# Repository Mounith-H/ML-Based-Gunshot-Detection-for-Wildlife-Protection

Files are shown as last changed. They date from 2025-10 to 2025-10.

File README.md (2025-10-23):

# AI-Powered Edge Gunshot Detection for Wildlife Protection

## Short summary
This repository contains firmware, hardware integration code, and supporting artifacts for an edge device that detects gunshot-like events using a Raspberry Pi Pico. The device performs on-device audio capture and inference, attaches GPS coordinates, and reports events over an NRF24L01 wireless link. The primary goals are real-time detection, low power operation, and field deployability for anti-poaching monitoring.

## Status
- Development: Feature-complete for core sensing, radio communication, GPS and power management on the Pico hardware.
- Machine learning: A TensorFlow Lite quantized model and export artifacts are provided; on-device inference integration is in progress.

Key completed items
- Audio input: INMP441 I2S microphone with PIO/DMA sampling.
- Location: NEO-6M GPS integration and basic NMEA parsing.
- Radio: NRF24L01 packet transmission with fragmentation and retries.
- Power: IP5306 power management using a PIO-driven PWM (continuous KEY pulsing) for reliable operation.
- Architecture: Dual-core Pico split (system/core tasks and audio/inference tasks) with robust initialization and error handling.

Planned / in development
- Finalize TensorFlow Lite inference on Pico and optimize model runtime.
- Optional mesh networking, encryption and acknowledgments.

## Repository contents (high level)
- `Raspberry_pi_pico/`, `inference-app/` – Pico firmware and build files.
- `python/` – training artifacts, quantized model (`gunshot_model_quant.tflite`), and helper notebooks.
- `python/dataset/` – dataset organization (environment and gunshot recordings) used for model training (see Data Availability).
- `figures_data/`, `metrics/` – plots, model metrics and training logs.
- `PCB/`, `lib/` – hardware design files and helper libraries.

## Data Availability (journal-ready statement)
All code required to build and run the device is included in this repository. The following datasets and artifacts are available as follows:

- Trained model: A quantized TensorFlow Lite model is included in `python/gunshot_model_quant.tflite` and additional exported models are in `python/exported_models/`.
- Processed training artifacts (training logs, metrics, and figure data) are included in `figures_data/` and `metrics/`.
- Raw audio recordings used for training (environmental and gunshot audio) are not included in this repository because of size and privacy/ethical constraints. Access to raw audio may be provided on reasonable request to the corresponding author for research purposes, subject to data sharing agreements.

If you need the raw audio files, preprocessed feature dumps, or a permanent DOI for the dataset, please contact the project maintainers (see Contact below). We can provide guidance to reproduce the training from raw data using the Jupyter notebook `python/model_training_quantization_jupyter.ipynb`.

Assumptions: The repository contains the trained model and training outputs, but large raw audio datasets are hosted externally or provided upon request. If you will publish this work in a journal and require a public dataset DOI, please tell us and we can prepare a dataset package for deposition (not currently included in this repo).

## Hardware
Components used in development
- Raspberry Pi Pico
- INMP441 digital microphone (I2S)
- NEO-6M GPS module
- NRF24L01 radio module
- IP5306 power-management IC

Power handling notes
- IP5306 `KEY` pin is driven by a PIO-based PWM to keep the power module enabled. The firmware contains a PIO state machine that pulses the `KEY` line with sufficient frequency and duty cycle to maintain power without manual intervention.
## Build and usage (Pico firmware)

Prerequisites

1. CMake >= 3.12
2. Raspberry Pi Pico SDK installed and `PICO_SDK_PATH` set in your environment

Quick build

1. From the firmware directory (for example `Raspberry_pi_pico/` or `inference-app/`):
   - mkdir build
   - cd build
   - cmake ..
   - make (or your platform's build tool)

2. Flashing

- Put the Pico into BOOTSEL mode and copy the generated `.uf2` file onto the Pico mass-storage device.

For exact build steps see the subdirectory `Raspberry_pi_pico/README.md` or `inference-app/README.md` (if present).

## Reproducing training
- A Jupyter notebook `python/model_training_quantization_jupyter.ipynb` demonstrates model training and quantization steps used to generate the included TFLite model. Use the `python/` directory for scripts and artifacts.

## Data sources and citations
The training used a combination of publicly available environmental and gunshot audio datasets. Below are the sources and citation information (BibTeX and IEEE formats).

1) E. Aydemir, "Gunshot audio dataset," Kaggle, 2021. [Online]. Available: https://www.kaggle.com/datasets/emrahaydemr/gunshot-audio-dataset. [Accessed: Oct. 11, 2025].

2) R. Kabealo and S. J. Wyatt, "Gunshot/Gunfire Audio Dataset," Zenodo, Jul. 2022, doi: 10.5281/zenodo.7004819. [Online]. Available: https://doi.org/10.5281/zenodo.7004819. [Accessed: Oct. 11, 2025].

3) K. J. Piczak, "ESC: Dataset for Environmental Sound Classification," in Proc. 23rd Annual ACM Conference on Multimedia, Brisbane, Australia, Oct. 2015, pp. 1015–1018, doi: 10.1145/2733373.2806390. [Online]. Available: http://dl.acm.org/citation.cfm?doid=2733373.2806390. [Accessed: Oct. 11, 2025].

## License and contact
- License: See `LICENSE` at the repository root for license terms.
- Contact / corresponding author: add a preferred contact email or GitHub handle here.

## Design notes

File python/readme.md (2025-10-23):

for the dataset 

1. Clone the repository from GitHub:

```bash
git clone https://github.com/karolpiczak/ESC-50.git
```

2. Download the dataset from the provided link from kaggle:
```bash
https://www.kaggle.com/datasets/emrahaydemr/gunshot-audio-dataset
```

3. Download the dataset from the provided link from zenodo:
```bash
https://zenodo.org/records/7004819
```

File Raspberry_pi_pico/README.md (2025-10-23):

# Gunshot Detection System - Raspberry Pi Pico Implementation

This directory contains the Raspberry Pi Pico implementation of the ML-based gunshot detection system. The system uses PIO state machines for efficient peripheral control and implements real-time audio processing with machine learning capabilities.

## Directory Structure
```
├── CMakeLists.txt          # Main CMake configuration
├── gps_handler.*          # GPS module interface
├── gunshot_model.*        # TensorFlow Lite model interface
├── inmp441.pio           # PIO program for INMP441 microphone
├── model_handler.*        # ML model management
├── power_control.pio     # PIO program for IP5306 power control
├── Raspberry_pi_pico.cpp # Main application
└── time_utils.h          # Time management utilities
```

## Prerequisites
- [Raspberry Pi Pico SDK](https://github.com/raspberrypi/pico-sdk)
- CMake (version 3.12 or higher)
- C/C++ compiler (GCC for Linux, MSVC for Windows)
- Git
- Make (for Linux)

## Installation

### 1. Set Up Environment Variables
```bash
# For Linux
export PICO_SDK_PATH=/path/to/pico-sdk

# For Windows (PowerShell)
$env:PICO_SDK_PATH="C:\path\to\pico-sdk"
```

### 2. Install Required Libraries
For Linux:
```bash
chmod +x setup_linux.sh
./setup_linux.sh
```

For Windows:
```cmd
setup_windows.bat
```

This will install:
- minmea (GPS NMEA parser)
- NRF24L01 radio library
- TensorFlow Lite Micro

### 3. Build the Project
```bash
mkdir build
cd build
cmake ..
make
```

## Hardware Configuration

### Required Components
- Raspberry Pi Pico
- INMP441 MEMS Microphone
- NEO-6M GPS Module
- NRF24L01 Radio Module
- IP5306 Power Management IC

### Pin Connections

#### INMP441 Microphone
- VDD → 3.3V (Pin 36)
- GND → GND (Pin 38)
- SD → GP20 (Pin 26)
- SCK → GP18 (Pin 24)
- WS → GP19 (Pin 25)
- L/R → GND

#### GPS Module (NEO-6M)
- VCC → 3.3V (Pin 36)
- GND → GND (Pin 38)
- TX → GP9 (Pin 11)
- RX → GP8 (Pin 12)

#### NRF24L01
- VCC → 3.3V (Pin 36)
- GND → GND (Pin 38)
- SCK → GP2 (Pin 4)
- MOSI → GP3 (Pin 5)
- MISO → GP4 (Pin 6)
- CSN → GP5 (Pin 7)
- CE → GP6 (Pin 9)
- IRQ → GP7 (Pin 10)

#### Power Control (IP5306)
- KEY → GP17 (Pin 22)

## Key Features

### 1. Power Management
- PIO-based PWM control for IP5306
- Continuous KEY pin pulsing
- 16-bit resolution for smooth control
- Automatic power maintenance

### 2. Audio Processing
- Real-time audio sampling via PIO
- DMA-based data transfer
- Configurable sampling rate
- Efficient ring buffer implementation

### 3. GPS Integration
- NMEA message parsing
- Position and time synchronization
- Configurable update rate
- Low-power operation support

### 4. Wireless Communication
- Packet fragmentation
- Automatic retry mechanism
- Mesh network capability
- Error detection and correction

## Development Notes

### Adding New Features
1. Create new source files in the root directory
2. Update CMakeLists.txt to include new sources
3. Run CMake configuration again

### Debugging
- Serial output available on UART0 (USB)
- Debug prints can be enabled in CMakeLists.txt
- LED indicators for system status

### Power Optimization
- Core 1 can be disabled when not needed
- PIO programs are power-efficient
- GPS can be put into low-power mode
- Radio duty cycling implemented

## Common Issues and Solutions

### Build Issues
1. **CMake Error**: Ensure PICO_SDK_PATH is set correctly
2. **Compiler Error**: Check GCC/G++ installation
3. **Library Error**: Run setup_linux or setup_windows script again

### Hardware Issues
1. **No Power**: Check IP5306 connections and KEY signal
2. **No GPS Fix**: Ensure clear view of sky
3. **Radio Issues**: Check antenna and power supply

## Tasks
Available VS Code tasks:
- `Compile Project`: Builds the project
- `Run Project`: Loads program via picotool
- `Flash`: Programs via OpenOCD/CMSIS-DAP

## Contributing
1. Fork the repository
2. Create a feature branch
3. Make your changes
4. Submit a pull request

## License
This project is licensed under the MIT License - see the LICENSE file for details

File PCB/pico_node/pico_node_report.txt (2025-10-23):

PCB statistics report
=====================
- Date: Tue 10 Jun 2025 07:43:07 PM IST
- Project: pico_node
- Board name: pico_node

Board
-----
- Width: 100.0000 mm
- Height: 60.0000 mm
- Area: 6000.0000 mm²

Pads
----
- Through hole: 92
- SMD: 8
- Connector: 0
- NPTH: 0

Vias
----
- Through vias: 16
- Blind/buried: 0
- Micro vias: 0

Components
----------

| | Front Side | Back Side | Total |
|---|---|---|---|
|THT: | 16 | 0 | 16 |
|SMD: | 0 | 3 | 3 |
|Unspecified:  | 0 | 0 | 0 |
|Total: | 16 | 3 | 19 |

Drill holes
-----------

| Count | Shape | X Size | Y Size | Plated | Via/Pad | Start Layer | Stop Layer |
|---|---|---|---|---|---|---|---|
| 79 | Round | 1.0000 mm | 1.0000 mm | PTH | Pad | F.Cu | B.Cu |
| 16 | Round | 0.7000 mm | 0.7000 mm | PTH | Via | F.Cu | B.Cu |
| 9 | Round | 0.8000 mm | 0.8000 mm | PTH | Pad | F.Cu | B.Cu |
| 4 | Round | 0.9000 mm | 0.9000 mm | PTH | Pad | F.Cu | B.Cu |

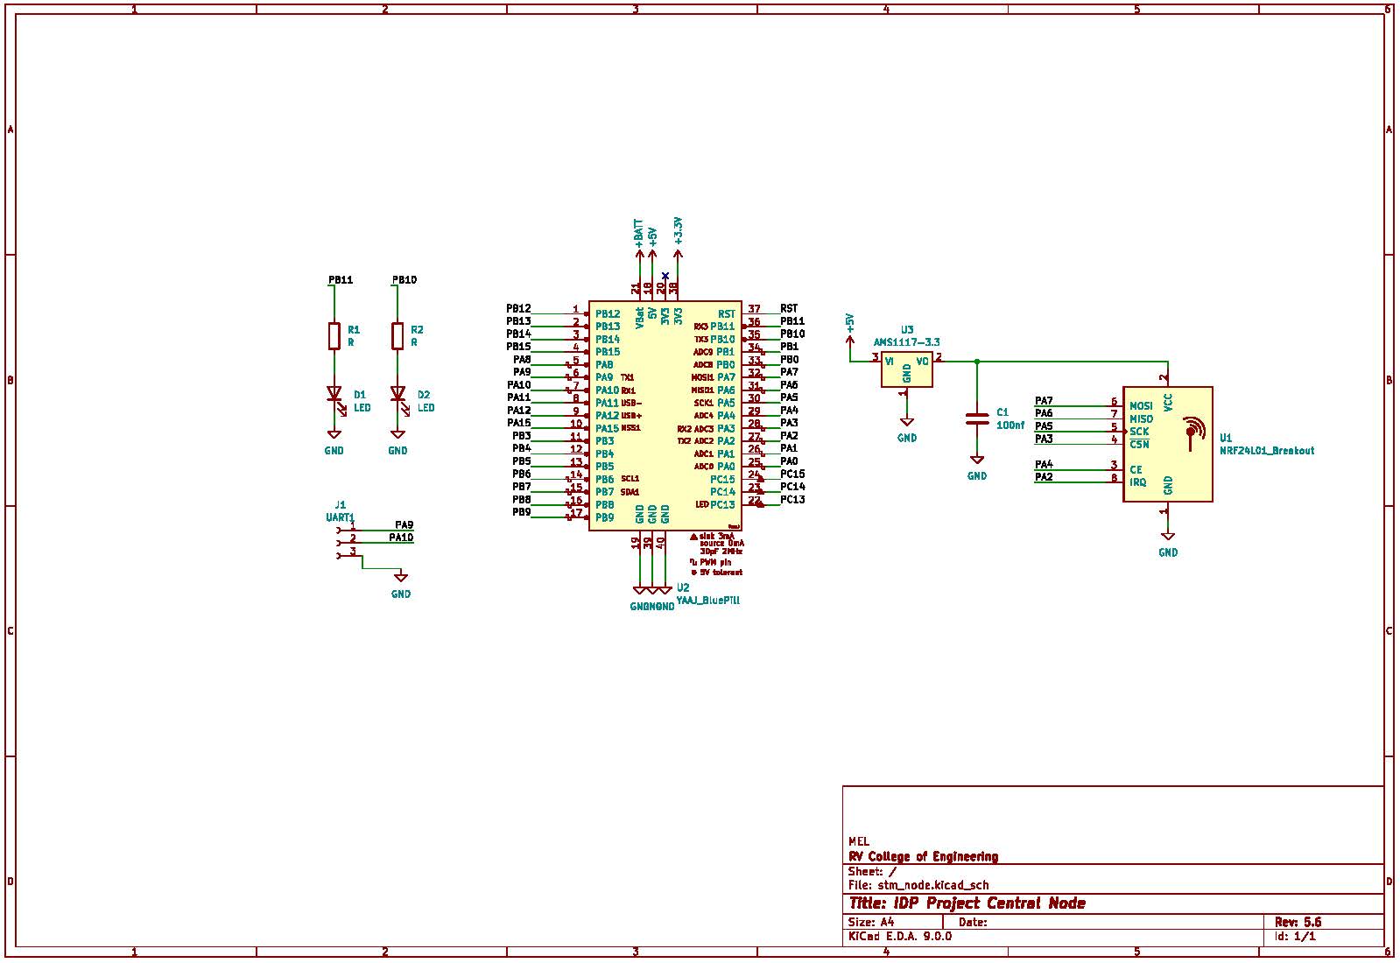
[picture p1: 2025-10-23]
PCB/stm_node/Schematic.jpg

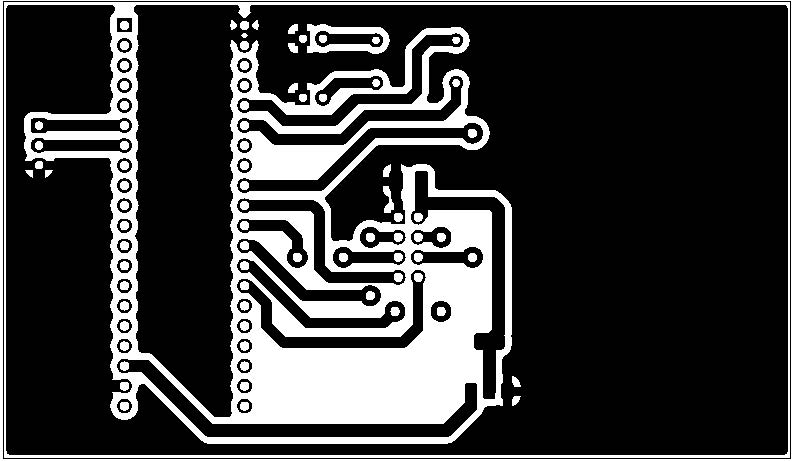
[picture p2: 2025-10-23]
PCB/stm_node/Bottem_Layer.jpg

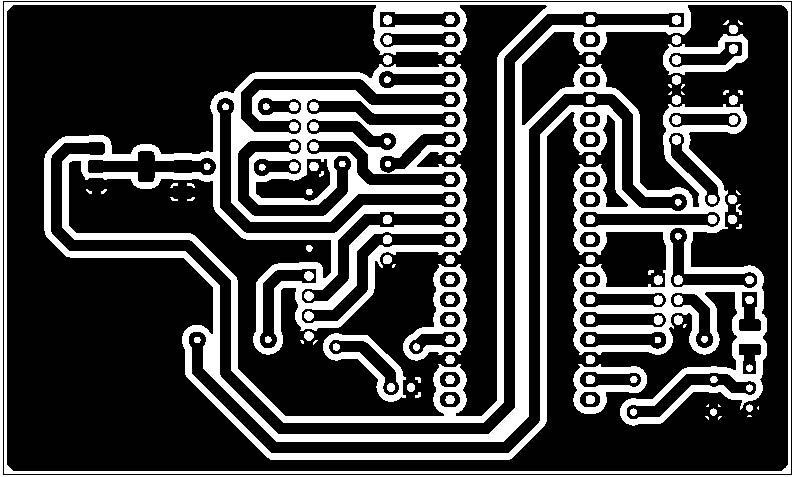
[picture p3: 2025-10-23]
PCB/pico_node/Bottem_Layer.jpg

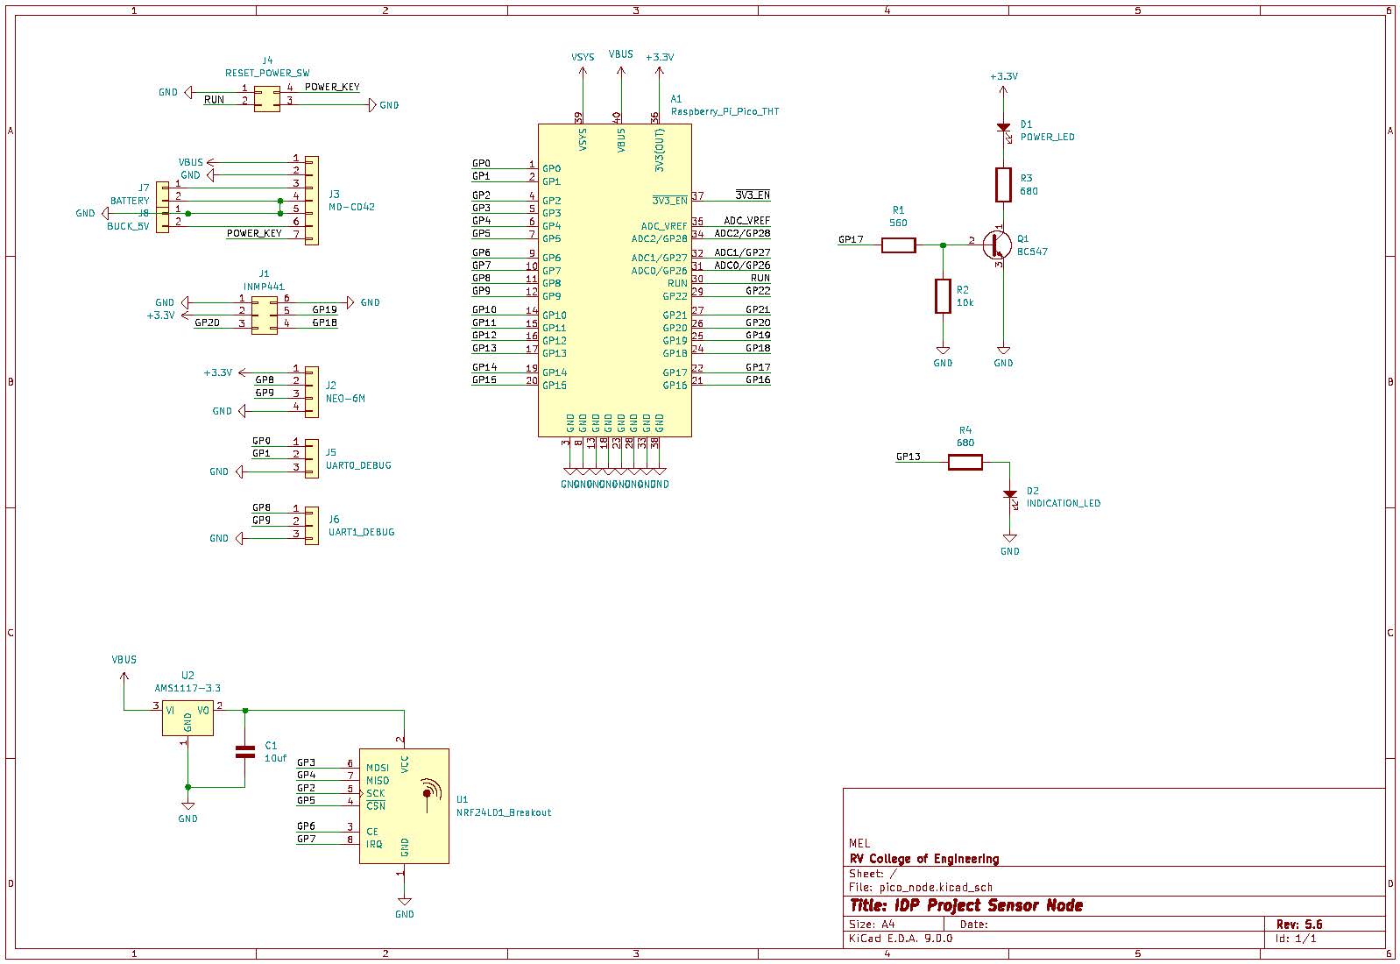
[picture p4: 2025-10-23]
PCB/pico_node/Schemantic.jpg

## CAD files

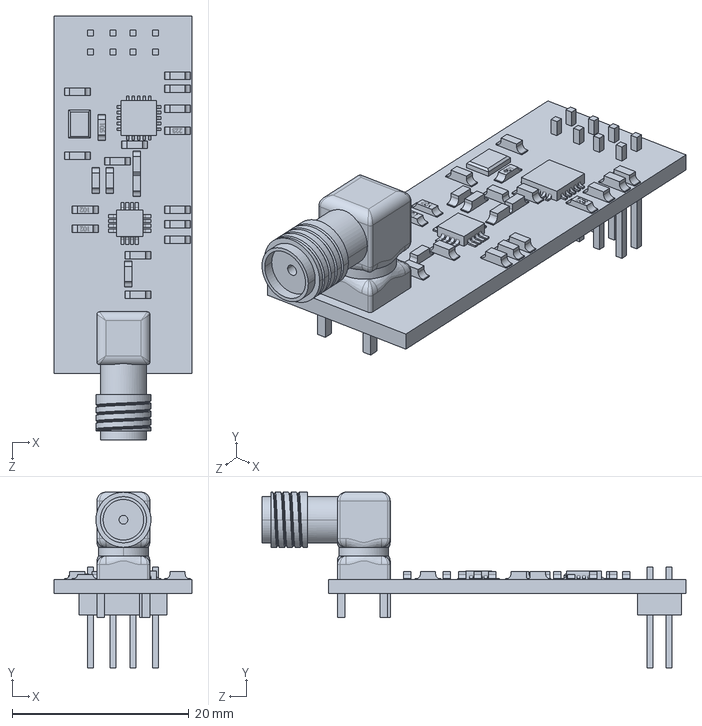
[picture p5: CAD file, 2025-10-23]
PCB/pico_node/3d_models/RF_TransmiterReciever.STEP
15.6 x 19.9 x 48.0 mm

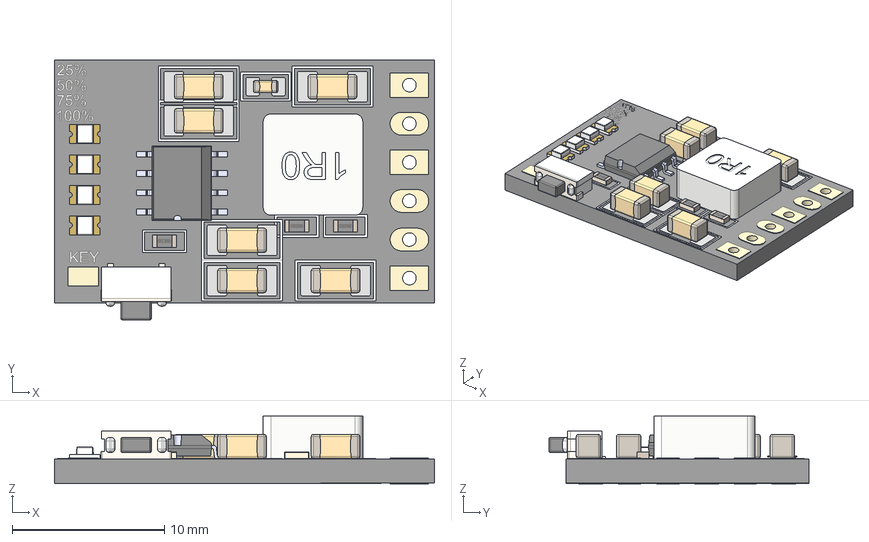
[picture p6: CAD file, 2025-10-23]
PCB/pico_node/3d_models/MH-CD42.step
25.0 x 17.1 x 4.47 mm
C1206 x 6
C0603
R0603 x 3
User Library-sop8_model_pin5to8_sop8 x 8
User Library-sop8_model_sop8_body
Light x 4
Anode Bottom x 4
Cathode Bottom x 4
Anode x 4
Cathode x 4
Base x 4
smt switch
1R0 Inductor
board

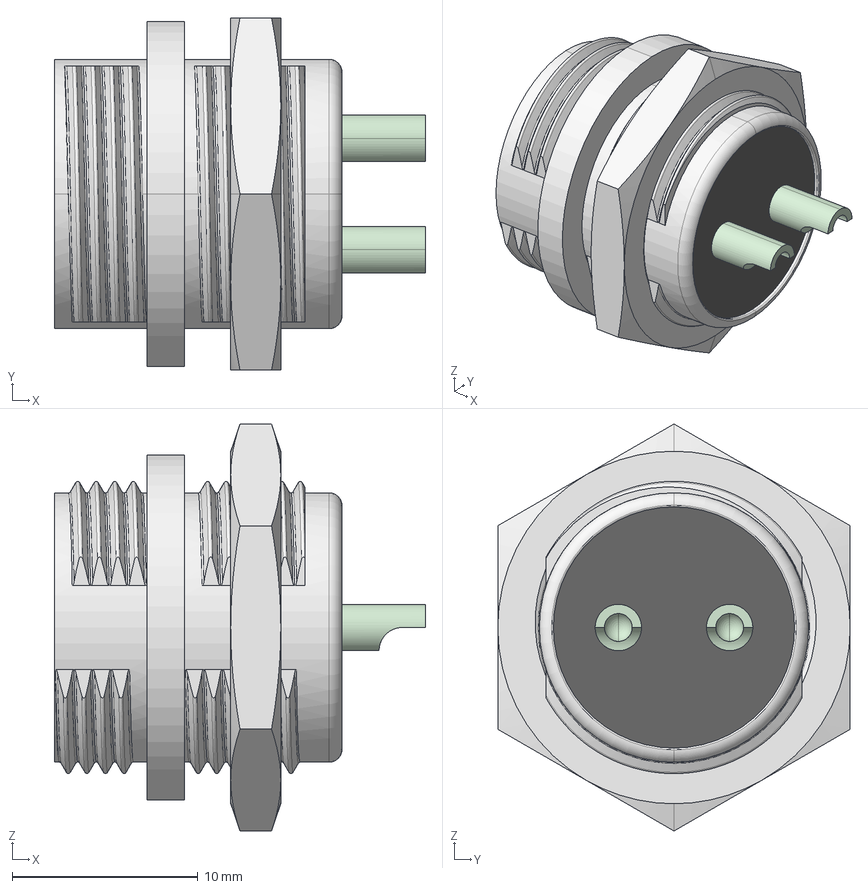
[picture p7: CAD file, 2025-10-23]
PCB/pico_node/3d_models/GX-16 Connector 2 Pins.stp
20.0 x 19.0 x 21.9 mm
Nut
Isolator
Pins

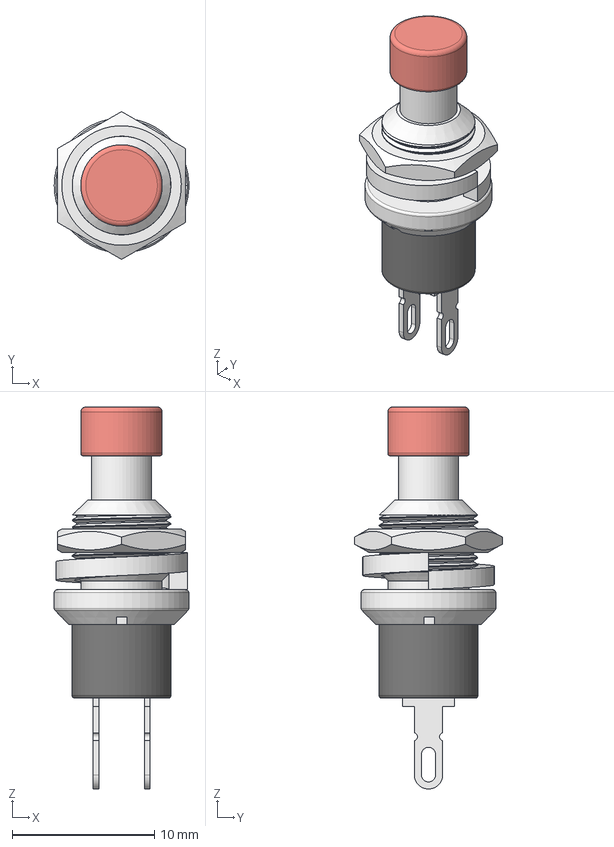
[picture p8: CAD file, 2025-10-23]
PCB/pico_node/3d_models/push_button_Switch_pannel_mount.step
9.46 x 10.4 x 26.8 mm
Plastic_korp
Metal_korp
Knopka_plast
Connectors
Grover
Gayko

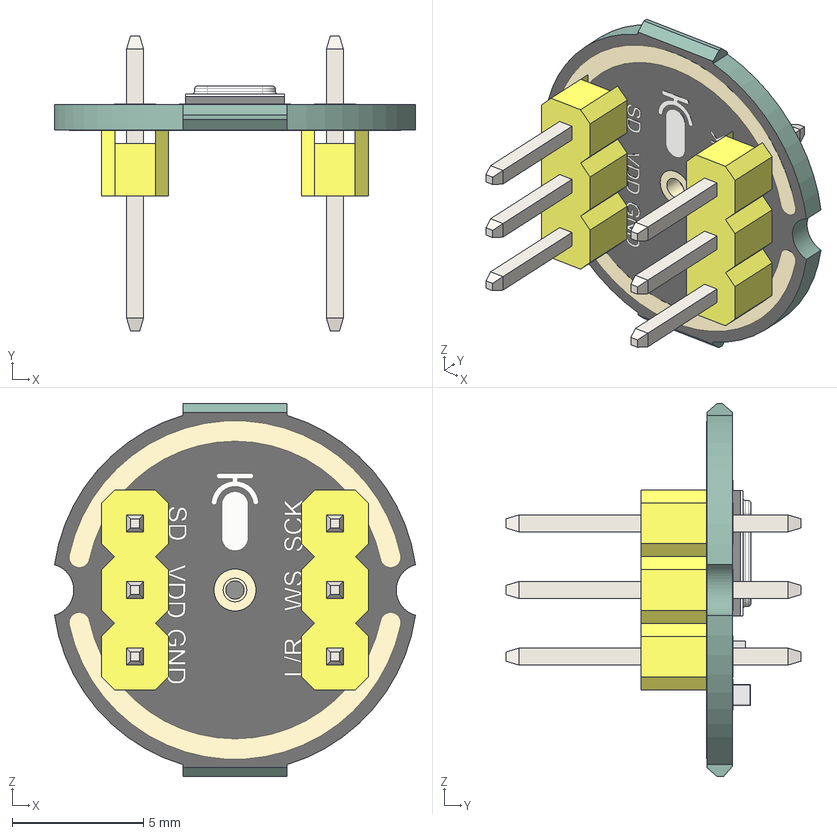
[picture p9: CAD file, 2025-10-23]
PCB/pico_node/3d_models/INMP441 I2S Microphone Module v15.step
13.8 x 11.2 x 14.2 mm
0603 Resistor

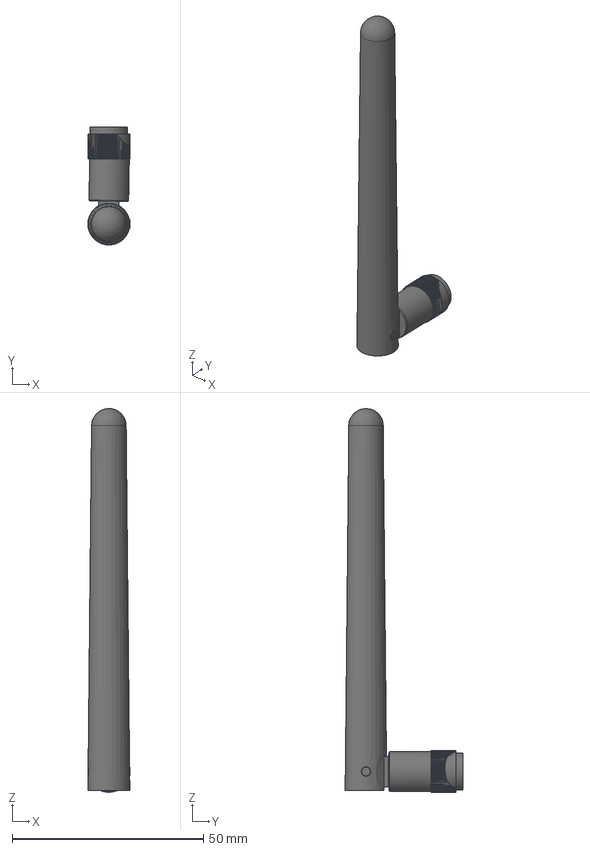
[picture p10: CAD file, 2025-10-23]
PCB/pico_node/3d_models/antenna_WiFi_RP-SMA_conn.step
11.1 x 30.9 x 100.5 mm
ant
conn_body
SMA_threads
socket

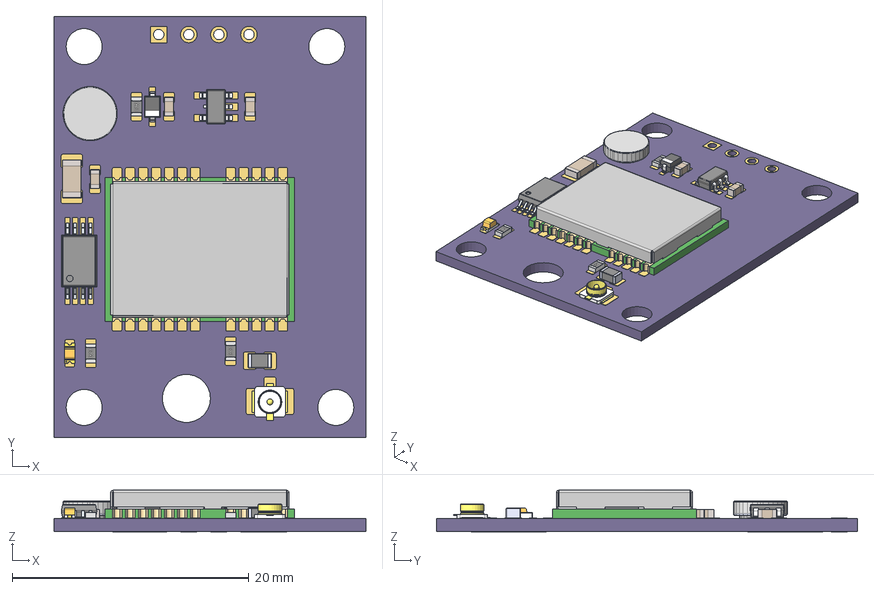
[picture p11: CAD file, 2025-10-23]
PCB/pico_node/3d_models/NEO-6M v2.step
26.3 x 35.6 x 3.51 mm
NEO-6M_v100
NEO-6M_v100-bottom
NEO-6M_v100-top

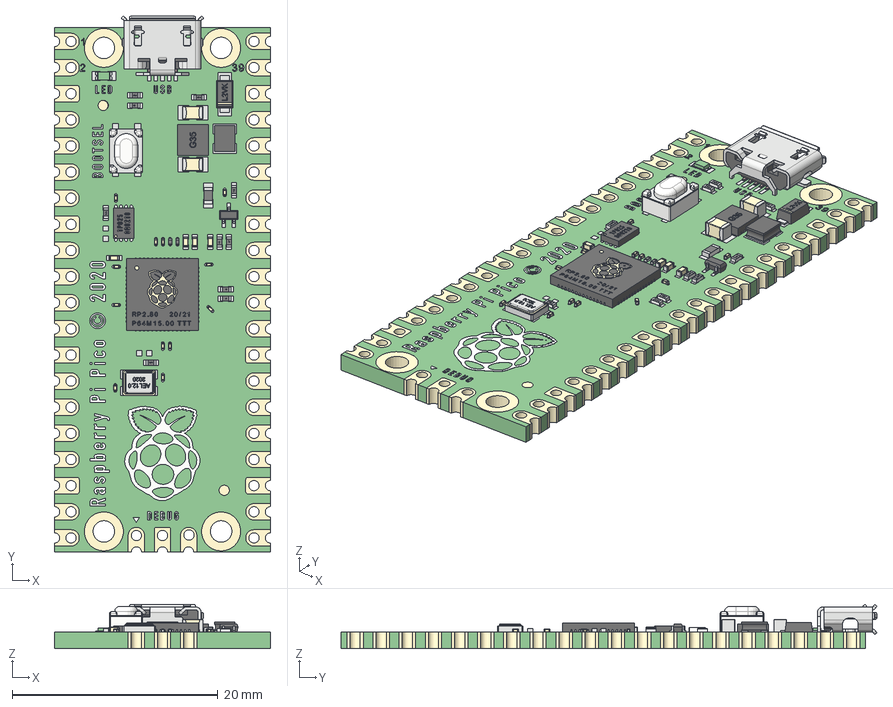
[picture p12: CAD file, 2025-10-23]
PCB/pico_node/3d_models/RaspBerryPi Pico.step
21.0 x 52.1 x 4.30 mm
RP2040
BOOTSEL
USB microB
R0603 x 2
R1005 x 11
R1608
RaspberryPi Pico_Solder
C1005 x 4
C0603 x 12
C2012 x 2
Crystal unit
Transistor
RT6150B-33GQW
MBR120VLSFT1G
L2520
LED1608_04
W25Q16JV_UX
RaspBerryPi Pico_CircuitBoard_logo

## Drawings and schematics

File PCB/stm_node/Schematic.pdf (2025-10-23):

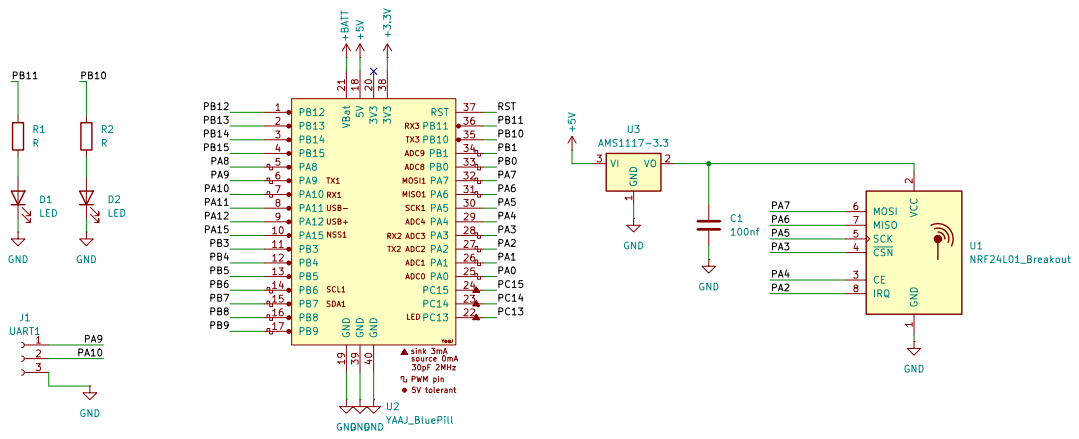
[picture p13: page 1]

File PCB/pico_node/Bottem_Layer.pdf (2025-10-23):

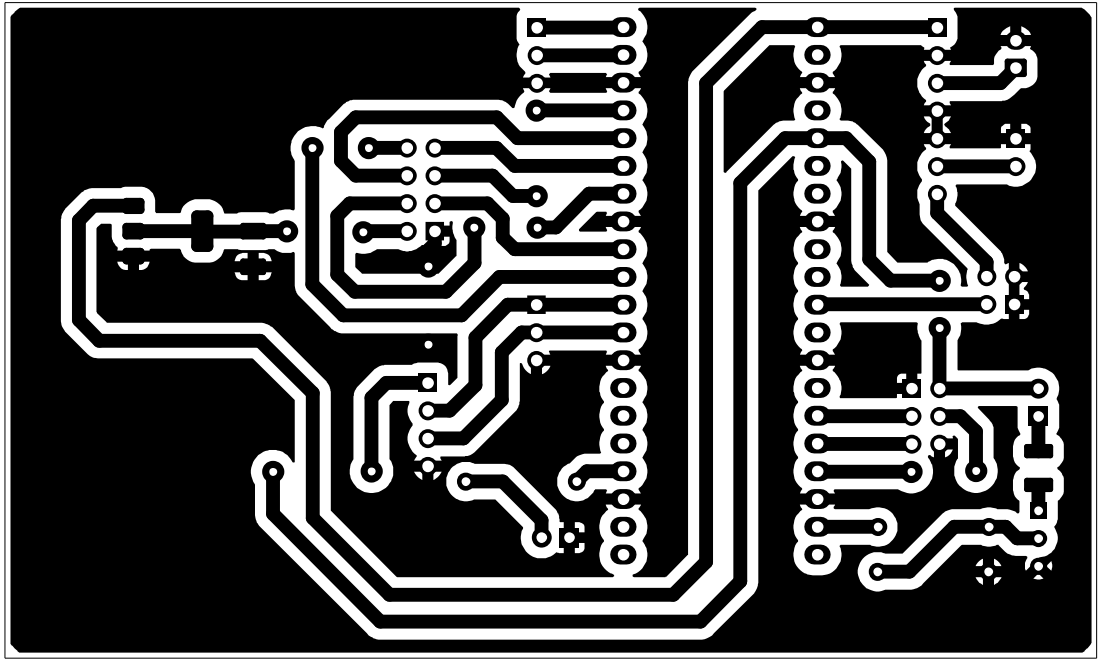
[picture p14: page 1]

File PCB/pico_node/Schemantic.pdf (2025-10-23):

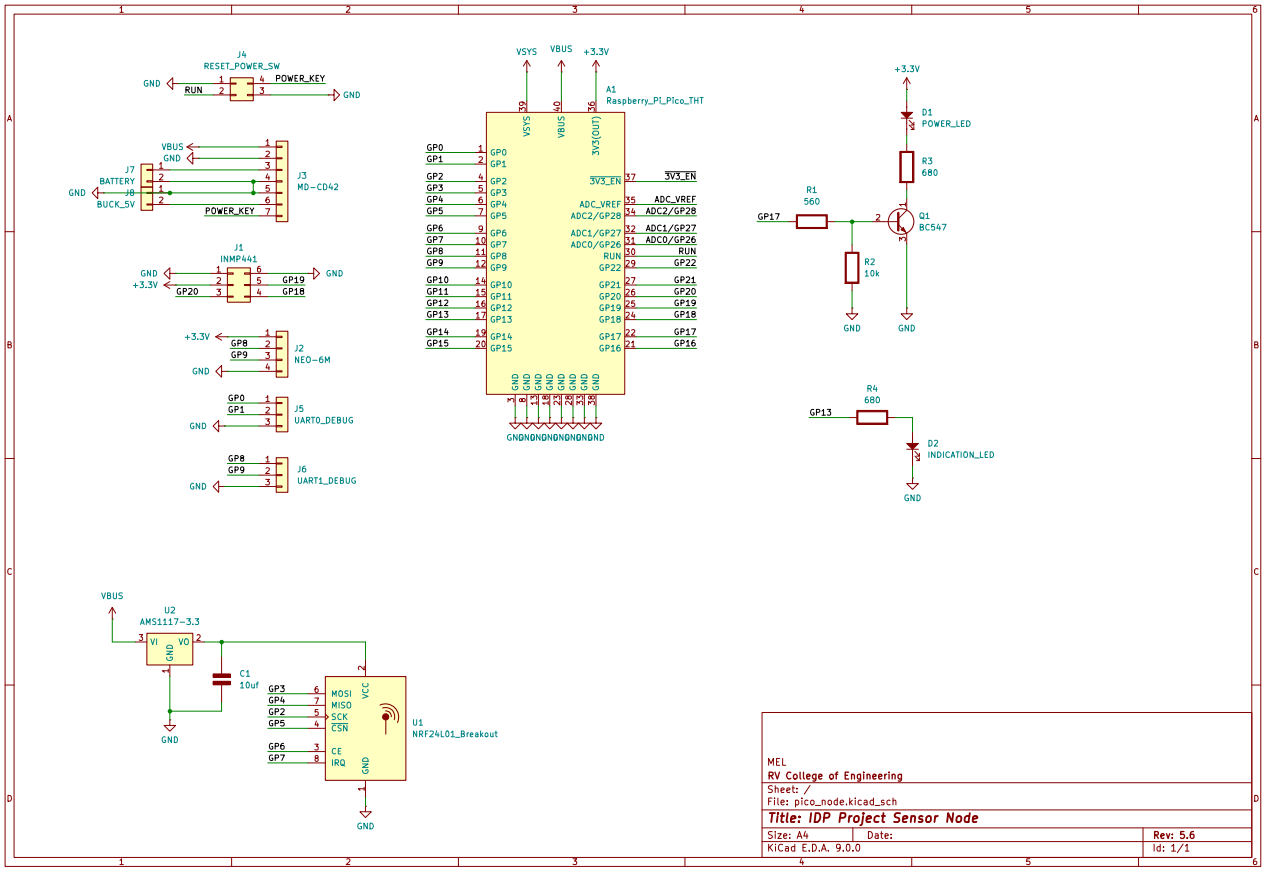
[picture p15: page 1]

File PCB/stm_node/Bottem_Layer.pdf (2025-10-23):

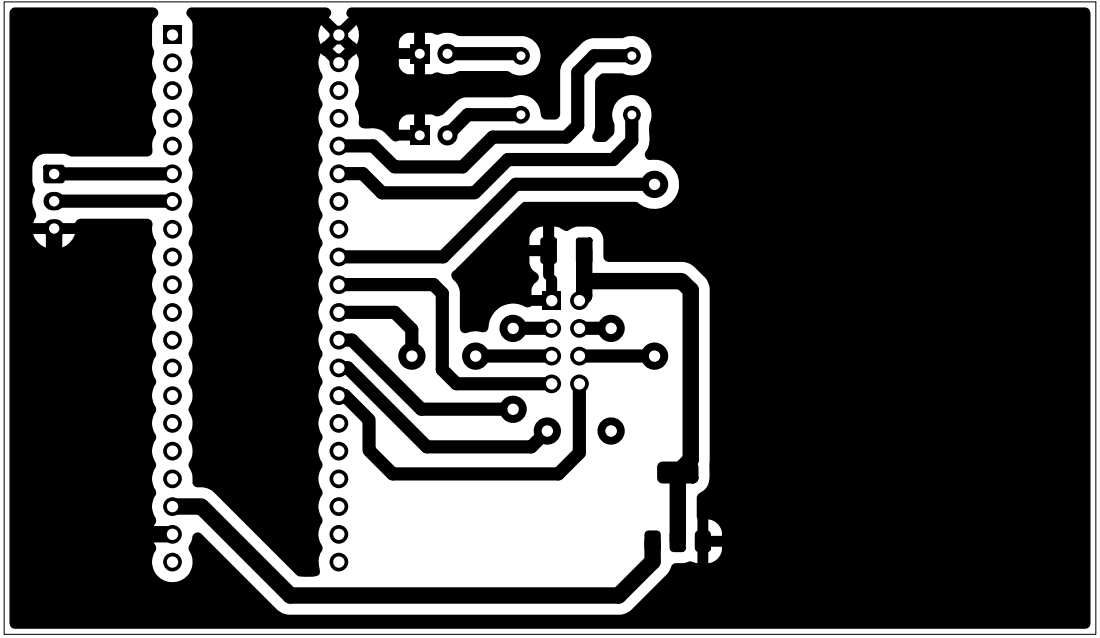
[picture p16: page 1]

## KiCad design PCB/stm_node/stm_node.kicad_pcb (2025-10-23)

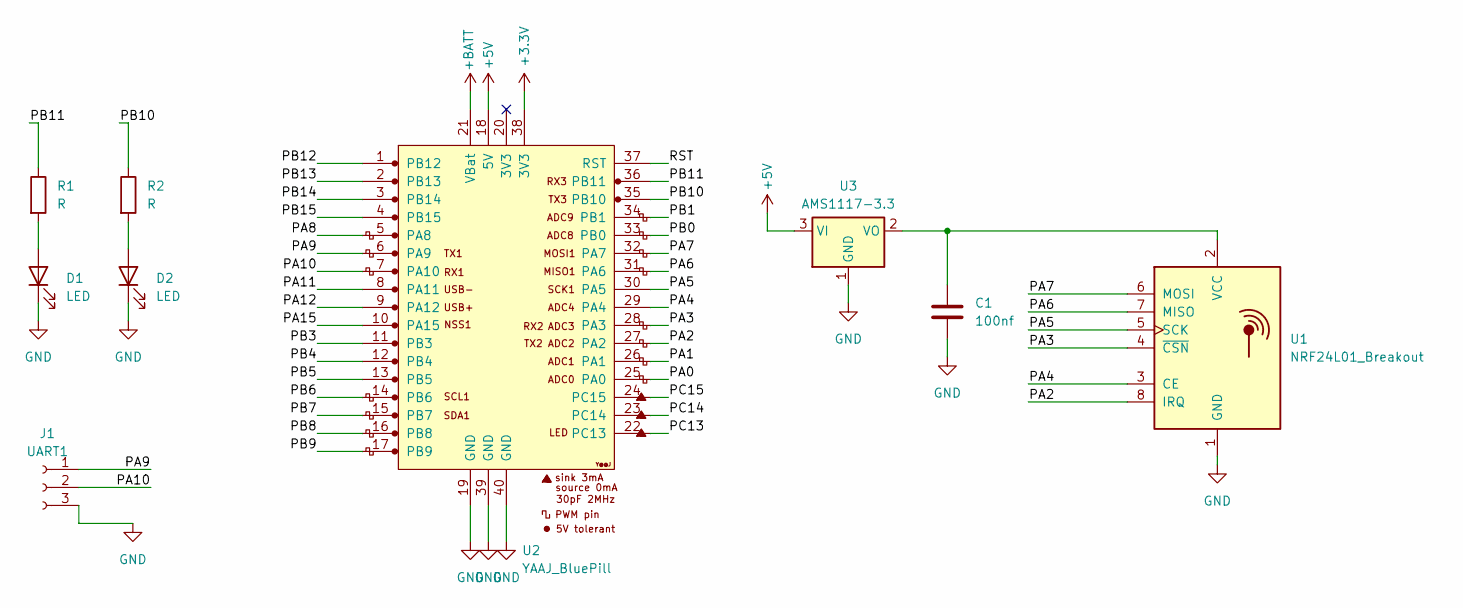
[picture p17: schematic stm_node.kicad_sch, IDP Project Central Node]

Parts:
C1: 100nf; CP_EIA-3528-12_Kemet-T_HandSolder
D1, D2: LED; LED_D5.0mm
J1: UART1; JST_XH_B3B-XH-A_1x03_P2.50mm_Vertical
R1, R2: R; R_Axial_DIN0207_L6.3mm_D2.5mm_P10.16mm_Horizontal
U1: NRF24L01_Breakout; nRF24L01_Breakout
U2: YAAJ_BluePill; YAAJ_BluePill_1
U3: AMS1117-3.3; SOT-223-3_TabPin2

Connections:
+3.3V: U2.38 (3V3)
+5V: U2.18 (5V), U3.3 (VI)
+BATT: U2.21 (VBat)
/PA0: U2.25 (PA0)
/PA1: U2.26 (PA1)
/PA2: U1.8 (IRQ), U2.27 (PA2)
/PA3: U1.4 (~CSN), U2.28 (PA3)
/PA4: U1.3 (CE), U2.29 (PA4)
/PA5: U1.5 (SCK), U2.30 (PA5)
/PA6: U1.7 (MISO), U2.31 (PA6)
/PA7: U1.6 (MOSI), U2.32 (PA7)
/PA8: U2.5 (PA8)
/PA9: J1.1, U2.6 (PA9)
/PA10: J1.2, U2.7 (PA10)
/PA11: U2.8 (PA11)
/PA12: U2.9 (PA12)
/PA15: U2.10 (PA15)
/PB0: U2.33 (PB0)
/PB1: U2.34 (PB1)
/PB3: U2.11 (PB3)
/PB4: U2.12 (PB4)
/PB5: U2.13 (PB5)
/PB6: U2.14 (PB6)
/PB7: U2.15 (PB7)
/PB8: U2.16 (PB8)
/PB9: U2.17 (PB9)
/PB10: R2.1, U2.35 (PB10)
/PB11: R1.1, U2.36 (PB11)
/PB12: U2.1 (PB12)
/PB13: U2.2 (PB13)
/PB14: U2.3 (PB14)
/PB15: U2.4 (PB15)
/PC13: U2.22 (PC13)
/PC14: U2.23 (PC14)
/PC15: U2.24 (PC15)
/RST: U2.37 (RST)
GND: C1.2, D1.1 (K), D2.1 (K), J1.3, U1.1 (GND), U2.19 (GND), U2.39 (GND), U2.40 (GND), U3.1 (GND)
unnamed: D1.2 (A), R1.2
unnamed: D2.2 (A), R2.2
unnamed: C1.1, U1.2 (VCC), U3.2 (VO)

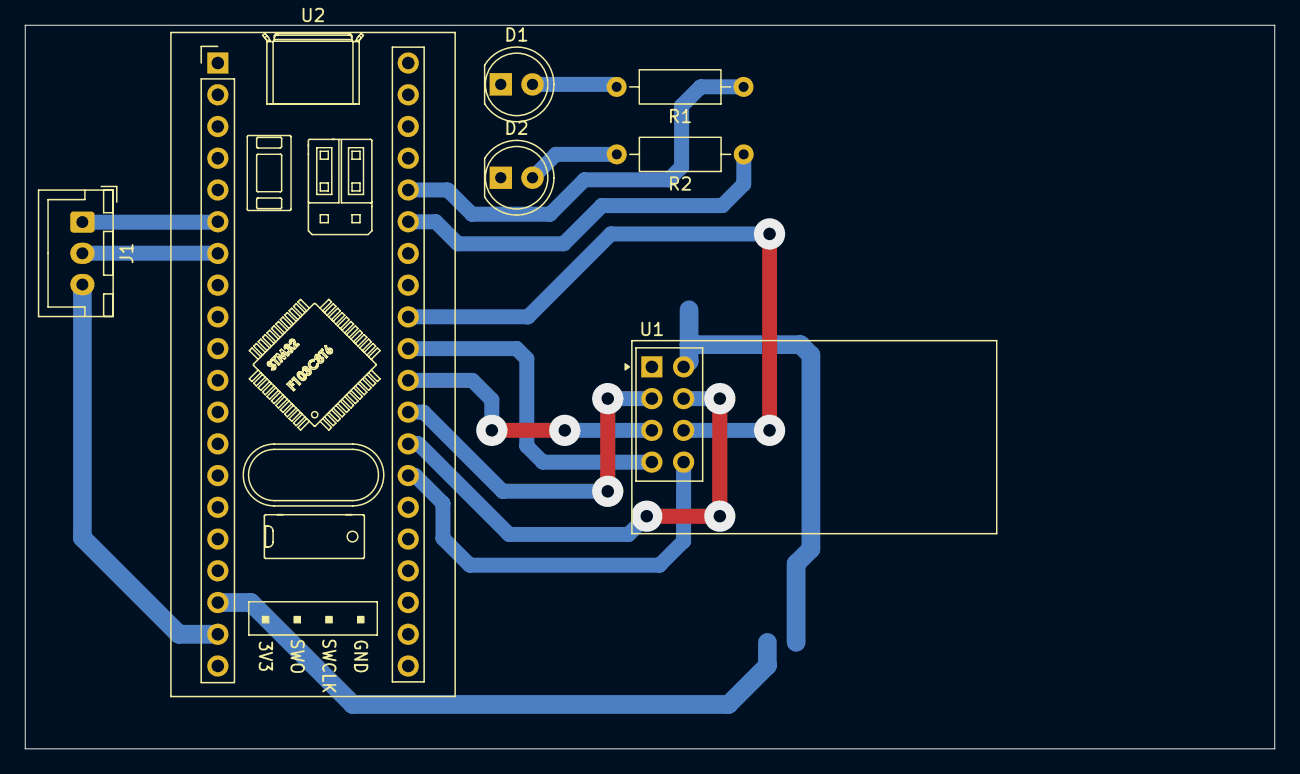
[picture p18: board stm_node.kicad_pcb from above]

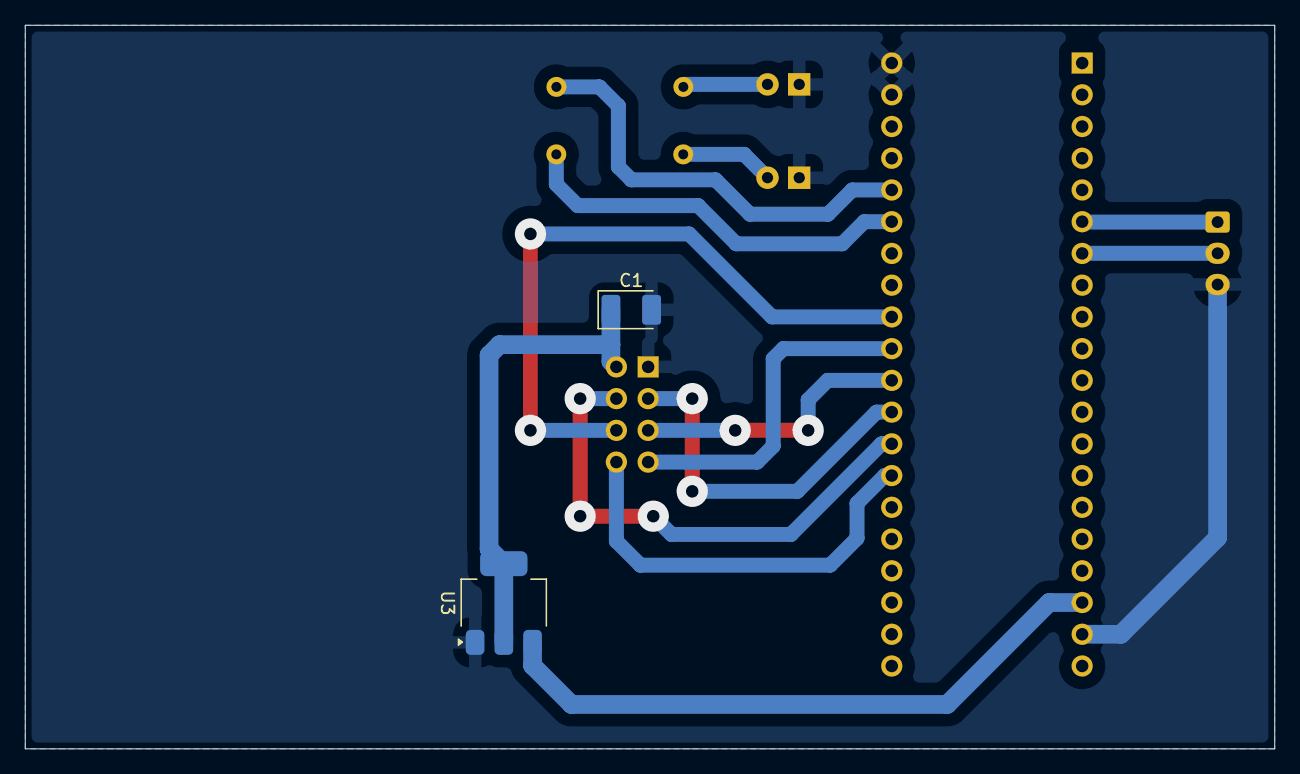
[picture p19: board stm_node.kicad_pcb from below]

Board: 2 copper layers, 100.0 x 57.9 mm, 9 parts (2 on the bottom side), 15 nets.

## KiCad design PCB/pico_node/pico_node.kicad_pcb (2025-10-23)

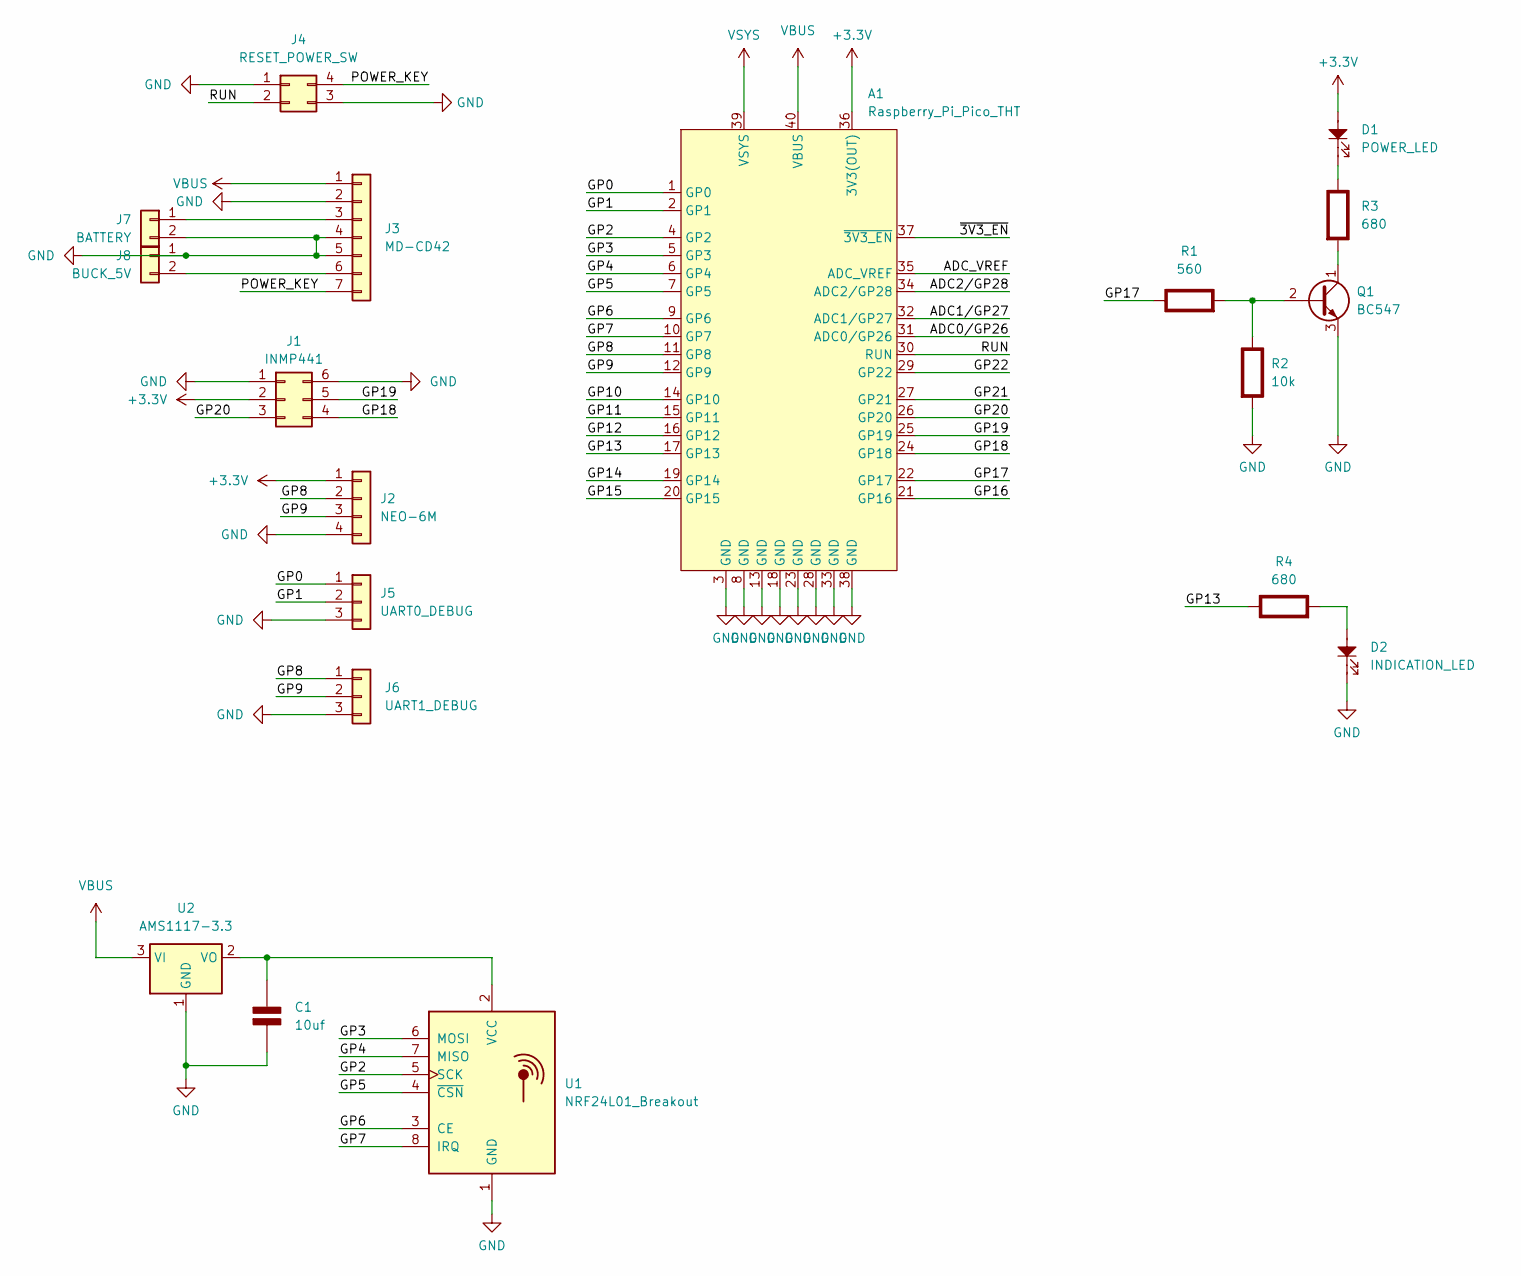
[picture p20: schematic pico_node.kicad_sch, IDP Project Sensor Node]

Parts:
A1: Raspberry_Pi_Pico_THT; raspberry_pi_pico_THT
C1: 10uf; CP_EIA-3528-21_Kemet-B_Pad1.50x2.35mm_HandSolder; Rating V
D1: POWER_LED; LED_D5.0mm
D2: INDICATION_LED; LED_D5.0mm
J1: INMP441; PinHeader_2x03_P2.54mm_Vertical
J2: NEO-6M; PinHeader_1x04_P2.54mm_Vertical
J3: MD-CD42; PinHeader_1x07_P2.54mm_Vertical
J4: RESET_POWER_SW; PinHeader_2x02_P2.54mm_Vertical
J5: UART0_DEBUG; PinHeader_1x03_P2.54mm_Vertical
J6: UART1_DEBUG; PinHeader_1x03_P2.54mm_Vertical
J7: BATTERY; JST_XH_B2B-XH-A_1x02_P2.50mm_Vertical
J8: BUCK_5V; PinSocket_1x02_P2.54mm_Vertical
Q1: BC547; TO-92_Inline_Wide
R1: 560; R_Axial_DIN0207_L6.3mm_D2.5mm_P10.16mm_Horizontal; Rating W
R2: 10k; R_Axial_DIN0207_L6.3mm_D2.5mm_P10.16mm_Horizontal; Rating W
R3: 680; R_1210_3225Metric_Pad1.30x2.65mm_HandSolder; Rating W
R4: 680; R_Axial_DIN0207_L6.3mm_D2.5mm_P10.16mm_Horizontal; Rating W
U1: NRF24L01_Breakout; nRF24L01_Breakout
U2: AMS1117-3.3; SOT-223-3_TabPin2

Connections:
+3.3V: A1.36 (3V3(OUT)), D1.2, J1.2, J2.1
/ADC0/GP26: A1.31 (ADC0/GP26)
/ADC1/GP27: A1.32 (ADC1/GP27)
/ADC2/GP28: A1.34 (ADC2/GP28)
/ADC_VREF: A1.35 (ADC_VREF)
/GP0: A1.1 (GP0), J5.1
/GP1: A1.2 (GP1), J5.2
/GP2: A1.4 (GP2), U1.5 (SCK)
/GP3: A1.5 (GP3), U1.6 (MOSI)
/GP4: A1.6 (GP4), U1.7 (MISO)
/GP5: A1.7 (GP5), U1.4 (~CSN)
/GP6: A1.9 (GP6), U1.3 (CE)
/GP7: A1.10 (GP7), U1.8 (IRQ)
/GP8: A1.11 (GP8), J2.2, J6.1
/GP9: A1.12 (GP9), J2.3, J6.2
/GP10: A1.14 (GP10)
/GP11: A1.15 (GP11)
/GP12: A1.16 (GP12)
/GP13: A1.17 (GP13), R4.1 (+)
/GP14: A1.19 (GP14)
/GP15: A1.20 (GP15)
/GP16: A1.21 (GP16)
/GP17: A1.22 (GP17), R1.1 (+)
/GP18: A1.24 (GP18), J1.4
/GP19: A1.25 (GP19), J1.5
/GP20: A1.26 (GP20), J1.3
/GP21: A1.27 (GP21)
/GP22: A1.29 (GP22)
/POWER_KEY: J3.7, J4.4
/RUN: A1.30 (RUN), J4.2
/~3V3_EN: A1.37 (~3V3_EN)
GND: A1.3 (GND), A1.8 (GND), A1.13 (GND), A1.18 (GND), A1.23 (GND), A1.28 (GND), A1.33 (GND), A1.38 (GND), C1.2 (-), D2.1, J1.1, J1.6, J2.4, J3.2, J3.4, J3.5, J4.1, J4.3, J5.3, J6.3, J7.2, J8.1, Q1.3 (E), R2.2 (-), U1.1 (GND), U2.1 (GND)
unnamed: C1.1 (+), U1.2 (VCC), U2.2 (VO)
unnamed: J3.3, J7.1
unnamed: J3.6, J8.2
unnamed: Q1.2 (B), R1.2 (-), R2.1 (+)
unnamed: Q1.1 (C), R3.2 (-)
unnamed: D1.1, R3.1 (+)
unnamed: D2.2, R4.2 (-)
VBUS: A1.40 (VBUS), J3.1, U2.3 (VI)
VSYS: A1.39 (VSYS)

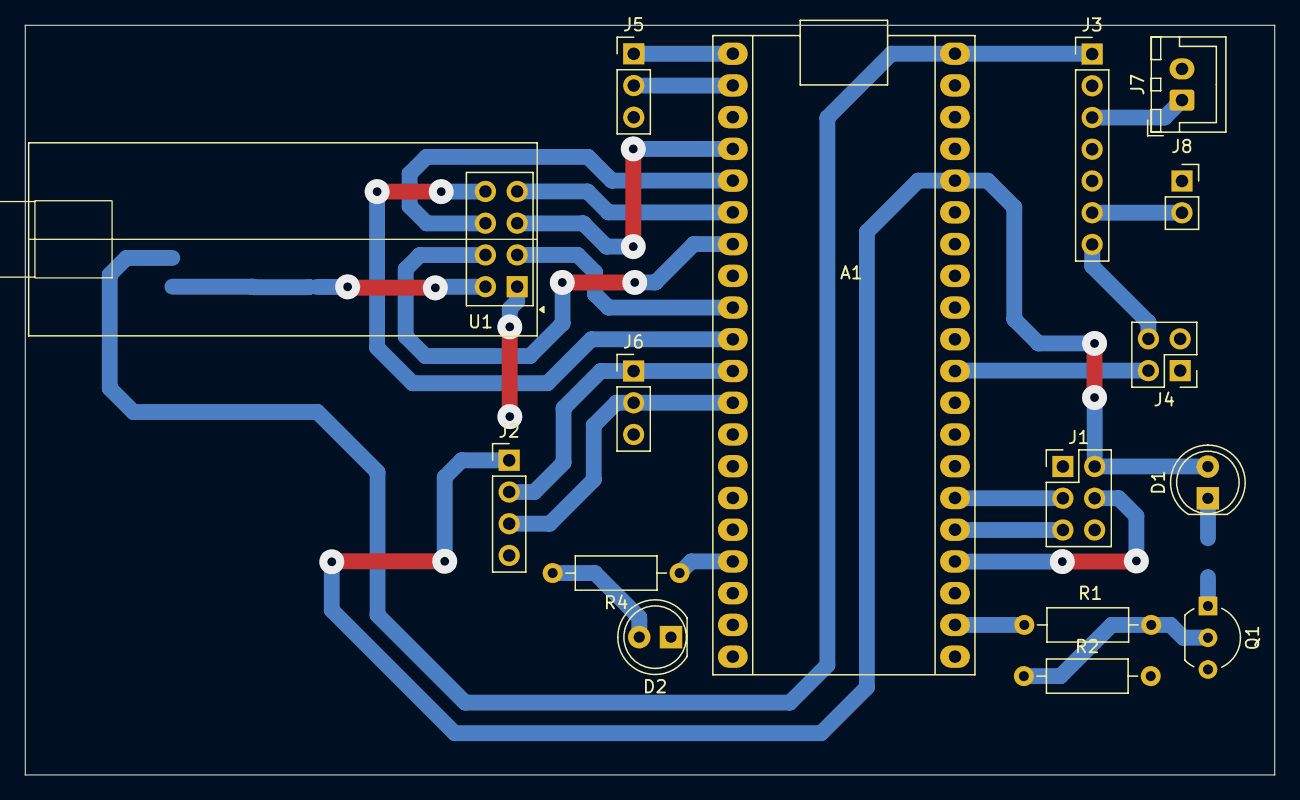
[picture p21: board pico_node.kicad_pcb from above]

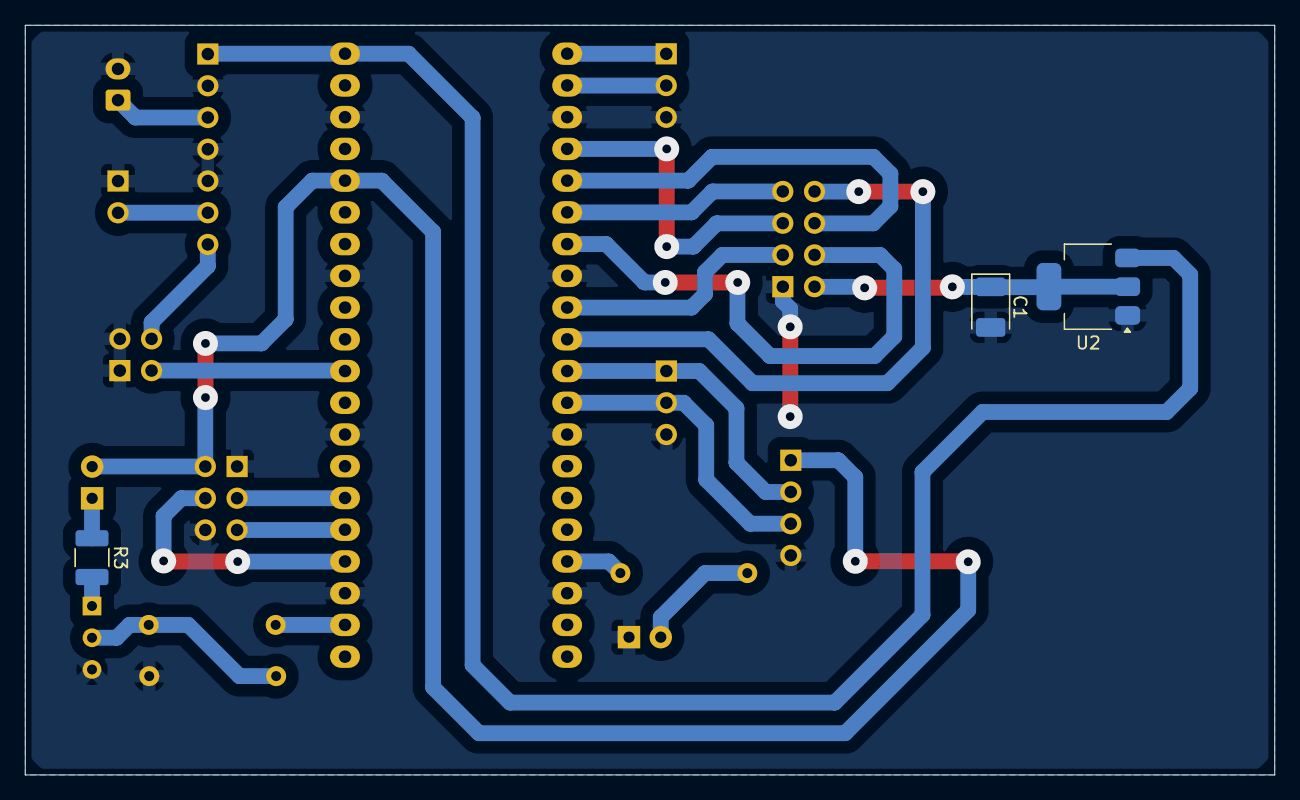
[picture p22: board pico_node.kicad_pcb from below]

Board: 2 copper layers, 100.0 x 60.0 mm, 19 parts (3 on the bottom side), 27 nets.

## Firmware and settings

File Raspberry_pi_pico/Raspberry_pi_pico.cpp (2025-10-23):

// Hardware Connections:
//
// INMP441 Microphone:
// - VDD  -> 3.3V (Pin 36 on Pico)
// - GND  -> GND  (Pin 38 on Pico)
// - SD   -> GP20 (Pin 26 on Pico) [DATA]
// - SCK  -> GP18 (Pin 24 on Pico) [BCLK]
// - WS   -> GP19 (Pin 25 on Pico) [LRCLK]
// - L/R  -> GND  (for left channel)
//
// LED Connection:
// - Anode   -> GP13 (Pin 17 on Pico) through a 220Ω resistor
// - Cathode -> GND  (any GND pin on Pico)
//
// FTDI Module Connection:
// - FTDI RX -> GP0 (Pin 1 on Pico, UART0 TX)
// - FTDI TX -> GP1 (Pin 2 on Pico, UART0 RX)
// - FTDI VCC -> 3.3V (Pin 36 on Pico)
// - FTDI GND -> GND (Pin 38 on Pico)
//
// NEO-6M GPS Module Connection:
// - VCC -> 3.3V (Pin 36 on Pico)
// - GND -> GND (Pin 38 on Pico)
// - TX  -> GP9 (Pin 11 on Pico, UART1 RX)
// - RX  -> GP8 (Pin 12 on Pico, UART1 TX)
//
// NRF24L01 Module Connection:
// - VCC -> 3.3V (Pin 36 on Pico)
// - GND -> GND (Pin 38 on Pico)
// - SCK -> GP2 (Pin 4 on Pico)
// - MOSI -> GP3 (Pin 5 on Pico)
// - MISO -> GP4 (Pin 6 on Pico)
// - CSN -> GP5 (Pin 7 on Pico)
// - CE -> GP6 (Pin 9 on Pico)
// - IRQ -> GP7 (Pin 10 on Pico) (optional, can be used for interrupts)
//
// Power Control MH-CD42 Module:
// - Key -> GP17 (Pin 22 on Pico) (PWM) [Very important, used to power to Pico]

#include <stdio.h>
#include <stdlib.h>
#include <stdarg.h>
#include <time.h>
#include <cstdio>
#include <string.h>  // For strncmp, memcpy, memset
#include <math.h>    // For fabs
#include <time.h>    // For time functions
#include "pico/stdlib.h"
#include "pico/multicore.h"
#include "pico/mutex.h"
#include "hardware/gpio.h"
#include "hardware/pio.h"
#include "hardware/dma.h"
#include "hardware/rtc.h"
#include "hardware/irq.h"
#include "hardware/clocks.h"
#include "hardware/uart.h"
#include "hardware/spi.h"
#include "pico_audio_recorder.h"
#include "power_control.pio.h"  // This will be generated from power_control.pio
#include "NRF24.h"
#include "edge-impulse-sdk/classifier/ei_run_classifier.h"

extern bool new_read_data;
extern int16_t *fw_ptr;

#define ENABLE_DEBUG 1
#define ENABLE_BOOTLOGO 1
#define ENABLE_GPS 1
#define ENABLE_NRF24 1

// Define the confidence threshold for gunshot detection --------------------------------------------
#define Confidence_THRESHOLD 0.8f
// --------------------------------------------------------------------------------------------------

#define UART_TX_PIN 0
#define UART_RX_PIN 1
#define UART_ID uart0
#define BAUD_RATE 115200
#define DATA_BITS 8
#define STOP_BITS 1
#define PARITY  UART_PARITY_NONE

#define LED_INBUILT_IN 25       // Built-in LED
#define LED_PIN 13              // External LED for indication

#define INMP441_SCK_PIN 18      // BCLK
#define INMP441_WS_PIN  19      // LRCLK/WS
#define INMP441_SD_PIN  20      // DATA

#define NRF_SPI_PORT spi0
#define NRF_SCK_PIN 2  // SPI Clock
#define NRF_MOSI_PIN 3 // SPI MOSI
#define NRF_MISO_PIN 4 // SPI MISO
#define NRF_CSN_PIN 5  // SPI Chip Select
#define NRF_CE_PIN 6   // Chip Enable
#define NRF_IRQ_PIN 7  // IRQ pin (optional)

// NRF24L01 Register Definitions
#define NRF_CONFIG      0x00
#define NRF_STATUS      0x07
#define NRF_RF_SETUP    0x06
#define NRF_RF_CH       0x05
#define NRF_TX_ADDR     0x10
#define NRF_RX_ADDR_P0  0x0A
#define NRF_FIFO_STATUS 0x17
#define NRF_R_REGISTER    0x00
#define NRF_W_REGISTER    0x20
#define NRF_NOP           0xFF
#define RF_DR_2MBPS     0x08  // 2 Mbps mode (default)
#define RF_DR_1MBPS     0x00  // 1 Mbps mode
#define RF_DR_250KBPS   0x20  // 250 kbps mode
#define RF_PWR_0DBM    0x06  // Maximum power: 0dBm
#define RF_PWR_NEG_6DBM  0x04  // -6dBm
#define RF_PWR_NEG_12DBM 0x02  // -12dBm
#define RF_PWR_NEG_18DBM 0x00  // Minimum power: -18dBm

// NRF24L01 Default Settings
#define NRF_CHANNEL 2  // Default channel for NRF24L01 (2.4GHz band)
#define NODE_ID "01"    // Node identifier
#define MAX_PAYLOAD_SIZE 24  // NRF24L01 max payload size (increased from 10 to 24)

#define GPS_UART_ID uart1
#define GPS_UART_TX_PIN 8
#define GPS_UART_RX_PIN 9
#define GPS_BAUD_RATE 9600
#define GPS_DATA_BITS 8
#define GPS_STOP_BITS 1
#define GPS_PARITY    UART_PARITY_NONE
#define GPS_BUFFER_SIZE 256

#define POWER_CONTROL_PIN 17   // Key pin for MH-CD42 module
#define POWER_CONTROL_PIO pio1 // Using pio1 to avoid conflicts
#define POWER_CONTROL_SM 1     // State machine 1
#define POWER_FREQ 2           //  frequency
#define POWER_DUTY_CYCLE 30    // 50% duty cycle

// --------------------------- LOGO ---------------------------

#if ENABLE_BOOTLOGO
const char *logo = R"LOGO(
'##::::'##:'########:'##:::::::
 ###::'###: ##.....:: ##:::::::
 ####'####: ##::::::: ##:::::::
 ## ### ##: ######::: ##:::::::
 ##. #: ##: ##...:::: ##:::::::
 ##:.:: ##: ##::::::: ##:::::::
 ##:::: ##: ########: ########:
..:::::..::........::........::
)LOGO";
#endif
// --------------------------- LOGO ---------------------------


// GPS location structure
struct gps_location_t {
    bool valid;
    float latitude;
    float longitude;
} g_current_location = {false, 0.0f, 0.0f};

// Message structure for transmitting data
typedef struct {
    char node_id[3];        // 2 chars + null terminator
    uint16_t msg_id;        // Message ID (0-65535)
    char date[11];          // DD/MM/YYYY + null terminator
    char time[9];           // HH:MM:SS + null terminator
    char latitude[12];      // Including decimal point and sign
    char longitude[12];     // Including decimal point and sign
    float confidence;
} gunshot_message_t;

#define NMEA_GPRMC "$GPRMC"
#define NMEA_GPGGA "$GPGGA"

// GPS globals
static char gps_buffer[GPS_BUFFER_SIZE];
static uint line_pos = 0;  // Current position in line buffer
static mutex_t gps_mutex;
static bool start_of_sentence = false;
static uint32_t last_valid_sentence = 0;
static uint32_t sentence_count = 0;
static bool valid_gps_data = false;
static float latitude = 0.0f;
static float longitude = 0.0f;

// GPS date/time globals
static char gps_date[11] = "01/01/2025";  // DD/MM/YYYY format, default fallback
static char gps_time[9] = "00:00:00";    // HH:MM:SS format, default fallback
static char local_date[11] = "01/01/2025";  // Local date in DD/MM/YYYY format
static char local_time[9] = "00:00:00";    // Local time in HH:MM:SS format
static bool gps_datetime_valid = false;


// Inter-core communication variables
static volatile bool core1_ready = false;
static volatile float latest_confidence = 0.0f;
static volatile uint32_t gunshot_detections = 0;
static volatile bool gunshot_detected = false;

// Global variables and mutex
static mutex_t printf_mutex;
static mutex_t audio_mutex;  // Mutex for audio data sharing between cores

// Global message ID counter
static uint8_t g_message_id = 0;

// Global gunshot message ID counter
static uint16_t g_gunshot_msg_id = 1;  // Start from 1 for readability

bool led_on = false;


// Message fragment structure for reliable transmission
typedef struct {
    uint8_t msg_id;        // Message ID (0-255)
    uint8_t fragment_num;  // Current fragment number (0-based)
    uint8_t total_fragments; // Total number of fragments
    uint8_t data_length;   // Length of data in this fragment
    uint8_t data[20];      // Data payload (24 - 4 header bytes = 20 data bytes)
} fragment_packet_t;

uint8_t address[5] = {'g','y','r','o','c'};  // 5-byte address gyroc
NRF24 nrf(NRF_SPI_PORT, NRF_SCK_PIN, NRF_MOSI_PIN, NRF_MISO_PIN, NRF_CSN_PIN, NRF_CE_PIN, NRF_IRQ_PIN);


// Function declarations
void init_sync(void);
void init_uart(void);
void safe_uart_puts(const char* str);
void safe_printf(const char* format, ...);
bool init_ml_model();
void core1_entry(void);  // Core 1 entry point for ML processing
void display_boot_logo(void);
bool init_power_control(void);
void update_power_control(float freq, float duty_cycle);
void init_gps(void);
bool wait_for_gps_fix(uint32_t timeout_ms);
void process_gps(void);
bool parse_gprmc(const char* sentence, float* out_lat, float* out_lon, bool* out_valid);
float nmea_to_decimal_degrees(float nmea_coord, char direction);
void gps_uart_irq_handler();
void get_gps_datetime(char* date_out, char* time_out, bool* valid_out);
bool test_microphone();
void nrf24l01_send_message(const char* message);
void create_json_message(char* buffer, size_t buffer_size, const gunshot_message_t* msg);
int raw_feature_get_data(size_t offset, size_t length, float *out_ptr);
void init_nrf24(void);
void convert_utc_to_local_date_time(int utc_hour, int utc_min, int utc_sec, int utc_day, int utc_month, int utc_year, int offset_hour, int offset_min, char* out_time_str, char* out_date_str);

// Initialize power control
bool init_power_control(void) {
    safe_uart_puts("Initializing power control...\r\n");
    
    // Load power control program into PIO memory
    PIO pio = POWER_CONTROL_PIO;
    uint sm = POWER_CONTROL_SM;
    
    if (!pio_can_add_program(pio, &power_control_program)) {
        safe_uart_puts("Failed to load power control program - no memory\n");
        return false;
    }
    
    uint offset = pio_add_program(pio, &power_control_program);
    
    // Calculate clock divider for desired frequency (1 kHz)
    // The period will be 2^16, so to get 1kHz:
    // CPU_freq / (desired_freq * 2^16) = clk_div
    uint clk_div = clock_get_hz(clk_sys) / (POWER_FREQ * (1u << 16));
    
    // Initialize the PWM program
    power_control_program_init(pio, sm, offset, POWER_CONTROL_PIN, clk_div);
    
    // Set the period (using full 16-bit resolution)
    uint32_t period = (1u << 16) - 1;
    uint32_t level = period / 2;  // 50% duty cycle
    
    power_control_set_period(pio, sm, period);
    power_control_set_level(pio, sm, level);
    
    safe_uart_puts("Power control initialized successfully\r\n");
    return true;
}

// Update power control settings (0-100 for duty cycle)
void update_power_control(float freq, float duty_cycle) {
    PIO pio = POWER_CONTROL_PIO;
    uint sm = POWER_CONTROL_SM;
    
    // Clamp duty cycle to valid range
    if (duty_cycle < 0.0f) duty_cycle = 0.0f;
    if (duty_cycle > 100.0f) duty_cycle = 100.0f;
    
    // Convert duty cycle percentage to level
    uint32_t period = (1u << 16) - 1;
    uint32_t level = (uint32_t)((duty_cycle / 100.0f) * period);
    
    // Update the PWM
    power_control_set_level(pio, sm, level);
}

void display_boot_logo(void) {
#if ENABLE_BOOTLOGO
    printf("%s\n", logo);
#endif
}

////------------- NRF Functions START ------------////

void init_nrf24(void) {
#if ENABLE_NRF24
    // Initialize NRF24L01 with the new comprehensive library
    // Initialize the radio
    if (!nrf.begin()) {
        printf("ERROR: Failed to initialize NRF24L01!\n");
        printf("Please check your wiring and power supply.\n");
        while (1) {
            // Fast blink to indicate error
            gpio_put(LED_INBUILT_IN, 1);
            sleep_ms(100);
            gpio_put(LED_INBUILT_IN, 0);
            sleep_ms(100);
        }
    }
    printf("NRF24L01 initialized successfully!\n");
    printf("Chip variant: NRF24L01%s\n", nrf.isConnected() ? "+" : "");    // Configure the radio to match STM32 receiver settings
    nrf.setPowerLevel(NRF24_POWER_LEVEL_NEG12DBM);    // Low power to match receiver
    nrf.setDataRate(NRF24_DATA_RATE_2MBPS);           // 2Mbps to match receiver
    nrf.setChannel(2);                                // Channel 2 to match STM32 receiver
    nrf.setCRCLength(NRF24_CRC_16BIT);                // 16-bit CRC to match receiver
    nrf.setAutoAck(true);                             // Enable auto-ack to match receiver
    nrf.setRetries(5, 15);                            // 5 retries with 4ms delay for reliability
    nrf.enableDynamicPayloads();                      // Enable dynamic payloads to match receiver
    uint8_t tx_address[] = {'g', 'y', 'r', 'o', 'c'};   // Set communication address (make sure this matches receiver address)
    nrf.openWritingPipe(tx_address);
    nrf.setModeTX();// Configure as transmitter
    printf("Radio Configuration:\n");
    printf("Channel: %d\n", nrf.getChannel());
    printf("Data Rate: 2Mbps\n");
    printf("Power Level: Low\n");
    printf("CRC Length: 16-bit\n");
    printf("Auto Ack: Enabled\n");
    printf("Dynamic Payloads: Enabled\n");
    printf("TX Address: %c%c%c%c%c\n", tx_address[0], tx_address[1], tx_address[2], tx_address[3], tx_address[4]);
    printf("\n=== DETAILED DEBUG INFO ===\n");
    nrf.printDetails();
    printf("============================\n\n");
    safe_uart_puts("NRF24L01 initialized successfully\r\n");
#endif
}

// Send message via NRF24L01 with fragmentation support
void nrf24l01_send_message(const char* message) {
    if (!message) return;
    
    size_t message_length = strlen(message);
    const uint8_t MAX_DATA_PER_FRAGMENT = 20; // 24 byte payload - 4 byte header
    
    // Calculate number of fragments needed
    size_t total_fragments = (message_length + MAX_DATA_PER_FRAGMENT - 1) / MAX_DATA_PER_FRAGMENT;
    
    // Limit to 255 fragments (uint8_t limit)
    if (total_fragments > 255) {
        // safe_uart_puts("ERROR: Message too long for fragmentation\r\n");
        return;
    }
    
    // Assign unique message ID
    uint8_t current_msg_id = g_message_id++;
    
    for (size_t fragment_num = 0; fragment_num < total_fragments; fragment_num++) {
        fragment_packet_t packet;
        
        // Set header
        packet.msg_id = current_msg_id;
        packet.fragment_num = fragment_num;
        packet.total_fragments = total_fragments;
        
        // Calculate data for this fragment
        size_t start_pos = fragment_num * MAX_DATA_PER_FRAGMENT;
        size_t remaining = message_length - start_pos;
        size_t data_length = (remaining > MAX_DATA_PER_FRAGMENT) ? MAX_DATA_PER_FRAGMENT : remaining;
        
        packet.data_length = data_length;
        
        // Copy data
        memset(packet.data, 0, sizeof(packet.data));
        memcpy(packet.data, message + start_pos, data_length);
        
        // Send fragment using the new NRF24 library
        bool success = nrf.write((uint8_t*)&packet, sizeof(fragment_packet_t));
        
        // Get detailed status information
        uint8_t status = nrf.getStatus();
        uint8_t observe_tx = nrf.getObserveTx();
        bool carrier = nrf.testCarrier();
        sleep_ms(50);
    }
}
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
int main() {
    stdio_init_all();
    display_boot_logo(); // Display boot logo if enabled
    init_sync();
    init_uart();
    sleep_ms(100);
    gpio_init(25); // led

    // Initialize power control first to ensure system stays powered
    if (!init_power_control()) {
        // If power control fails, try to indicate error with LED
        gpio_init(LED_INBUILT_IN);
        gpio_set_dir(LED_INBUILT_IN, GPIO_OUT);
        while(1) {
            gpio_put(LED_INBUILT_IN, !gpio_get(LED_INBUILT_IN));
            sleep_ms(100); // Fast blink to indicate error
        }
    }
    
    // Initialize LED for visual debugging
    gpio_init(LED_INBUILT_IN);
    gpio_set_dir(LED_INBUILT_IN, GPIO_OUT);
    gpio_put(LED_INBUILT_IN, true);
    gpio_init(LED_PIN);
    gpio_set_dir(LED_PIN, GPIO_OUT);
    gpio_put(LED_PIN, false); // Start with LED off


    init_gps();
    init_nrf24();
    
    safe_uart_puts("\r\n=== INMP441 + ML Gunshot Detection System (Dual Core) ===\r\n");
    safe_uart_puts("Core 0: Microphone initialization and LED control\r\n");
    safe_uart_puts("Core 1: ML processing and gunshot detection\r\n");
    
    // Initialize microphone on core 0
    safe_uart_puts("Initializing microphone on Core 0...\r\n");
    
    safe_uart_puts("Microphone initialized successfully on Core 0!\r\n");
    
    // Start Core 1 for ML processing
    safe_uart_puts("Starting Core 1 for ML processing...\r\n");
    multicore_launch_core1(core1_entry);
    
    // Wait for Core 1 to initialize
    safe_uart_puts("Waiting for Core 1 to initialize...\r\n");
    while (!core1_ready) {
        sleep_ms(100);
    }
    safe_uart_puts("Core 1 ready!\r\n");
    
    // Core 0 main loop - LED blinking based on gunshot detection
    safe_uart_puts("Core 0: Starting LED control loop...\r\n");
    uint32_t last_report = 0;
    uint32_t last_status = 0;
    uint32_t gunshot_count = 0;
    bool led_on_new = false;
    
    while (true) {  
        if (led_on) {
            last_report = to_ms_since_boot(get_absolute_time());
            led_on_new = true; // Turn on LED immediately
            gpio_put(LED_PIN, true);
            led_on = false; // Reset flag
        }
        if (led_on_new) {
            // LED on for 1 second, then off
            if (to_ms_since_boot(get_absolute_time()) - last_report >= 1000) {
                gpio_put(LED_PIN, false);
                led_on_new = false; // Turn off LED after 1 second
            }
        }

        // Check if gunshot was detected by Core 1
        if (gunshot_detected) {
            gunshot_count++;

            #if ENABLE_NRF24
                // Prepare and send message via NRF24L01
                gunshot_message_t msg;
                strncpy(msg.node_id, NODE_ID, sizeof(msg.node_id) - 1);
                msg.node_id[sizeof(msg.node_id) - 1] = '\0';  // Ensure null termination
                msg.msg_id = g_gunshot_msg_id++; // Assign unique message ID
                
                // Get GPS date/time if available, fallback to system time
                char gps_date_str[11];
                char gps_time_str[9];
                bool datetime_valid;
                get_gps_datetime(gps_date_str, gps_time_str, &datetime_valid);
                
                if (datetime_valid) {
                    // Use GPS date/time
                    strncpy(msg.date, gps_date_str, sizeof(msg.date) - 1);
                    strncpy(msg.time, gps_time_str, sizeof(msg.time) - 1);
                    msg.date[sizeof(msg.date) - 1] = '\0';
                    msg.time[sizeof(msg.time) - 1] = '\0';
                    printf("[EVENT] Using GPS date/time: %s %s\n", msg.date, msg.time);
                } else {
                    // Fallback to system time
                    time_t now = time(NULL);
                    struct tm *t = localtime(&now);
                    strftime(msg.date, sizeof(msg.date), "%d/%m/%Y", t);
                    strftime(msg.time, sizeof(msg.time), "%H:%M:%S", t);
                    printf("[EVENT] Using system date/time: %s %s\n", msg.date, msg.time);
                }
        
                snprintf(msg.latitude, sizeof(msg.latitude), "%.6f", latitude); // Set latitude, longitude, and confidence
                snprintf(msg.longitude, sizeof(msg.longitude), "%.6f", longitude);
                msg.confidence = latest_confidence;
                
                char json_buffer[1024];
                create_json_message(json_buffer, sizeof(json_buffer), &msg);// Create JSON message
                #if ENABLE_NRF24
                nrf24l01_send_message(json_buffer); // Send message with fragmentation
                led_on = true; // Set LED on flag
                #endif
            #endif
            gunshot_detected = false;// Reset the detection flag
        }
        
        // Print status every 30 seconds
        // uint32_t now = to_ms_since_boot(get_absolute_time());
        // if (now - last_status > 30000) {
        //     char buf[128];
        //     snprintf(buf, sizeof(buf), "Core 0: System status - Gunshots detected: %lu, GPS valid: %s\r\n", 
        //              gunshot_count, g_current_location.valid ? "YES" : "NO");
        //     safe_uart_puts(buf);
        //     last_status = now;
        // }
        
        sleep_ms(50); // Check for events every 50ms
    }

    return 0;
}

// Initialize ML model for gunshot detection
bool init_ml_model() {
    safe_uart_puts("Initializing ML model...\r\n");
    
    return true;
}

// Function to get raw feature data from the firmware pointer
int raw_feature_get_data(size_t offset, size_t length, float *out_ptr) {
    // for (size_t i = 0; i < length; i++) {
    //     // >> 8 removes least-significant 8 bits from 24-bit INMP441 data
    //     int16_t sample = (int16_t)(fw_ptr[offset + i] >> 8);
    //     out_ptr[i] = (float)sample / 32768.0f; // Normalize to -1.0 to 1.0
    // }
    // return 0;

    numpy::int16_to_float(fw_ptr+offset, out_ptr, length);
    return 0;
}

// Core 1 entry point - handles all ML processing
void core1_entry() {
    safe_uart_puts("Core 1: Starting ML processing...\r\n");
    run_classifier_init();
    EI_IMPULSE_ERROR res;
    ei_impulse_result_t result = {nullptr};
    signal_t features_signal;
    features_signal.total_length = EI_CLASSIFIER_SLICE_SIZE;
    features_signal.get_data = &raw_feature_get_data;
    inmp441_pio_init(INMP441_pio, INMP441_SM, INMP441_SD, INMP441_SCK, INMP441_SAMPLE_RATE);
    safe_uart_puts("Core 1: Ready for ML processing!\r\n");
    // Core 1 main loop - ML processing
    uint8_t f_idx=0;
    core1_ready = true;  // Signal core0 even on failure so it doesn't hang
    while (true) {
        if (new_read_data) {
            new_read_data = false;

            if (++f_idx >= (EI_CLASSIFIER_SLICES_PER_MODEL_WINDOW)) {
                res = run_classifier_continuous(&features_signal, &result, false, true);
                if (res != EI_IMPULSE_OK) ei_printf("ERR: Failed to run classifier (%d)\n", res);
                ei_printf("%s:%.5f, ", ei_classifier_inferencing_categories[0], result.classification[0].value);
                ei_printf("%s:%.5f\r\n", ei_classifier_inferencing_categories[1], result.classification[1].value);
                if((ei_classifier_inferencing_categories[1] == "gunshot") && (result.classification[1].value > Confidence_THRESHOLD)) {
                    latest_confidence = result.classification[1].value;
                    gunshot_detected = true;
                    printf("Gunshot detected!\n");
                }
                f_idx=0;
            }
        }
    sleep_ms(10);
    }
}

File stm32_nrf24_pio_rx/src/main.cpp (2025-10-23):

#include <Arduino.h>
#include <SPI.h>
#include "printf.h"
#include "RF24.h"

#define siran_pin PB10 // Pin for Siran mode
#define LED_PIN PB11 // Pin for LED indication

RF24 radio(PA4, PA3);  // using pin PA4 for the CE pin, and pin PA3 for the CSN pin
// IRQ pin is connected to PA2 but not used in this basic example

// Debug serial on PA9 (TX) and PA10 (RX) - Hardware Serial2
HardwareSerial DebugSerial(PA10, PA9); // RX, TX pins

// Data reconstruction variables
String completeMessage = "";
unsigned long lastPacketTime = 0;
const unsigned long PACKET_TIMEOUT = 5000; // 5 seconds timeout between packets
int fragmentCount = 0;
int expectedFragments = 0; // Will be set from header
int currentMessageId = -1;

int lastUpdateTime = 0; // Last update time for Siran mode
bool siranEnabled = false; // Siran mode enabled flag

void parseAndDisplayData(String jsonData);
void siran();

void setup() {
  Serial.begin(115200);      // USB Serial - for JSON output only
  DebugSerial.begin(115200); // Debug Serial on PA9/PA10 - for debug messages
  
  pinMode(PC13, OUTPUT); // LED pin for indication
  pinMode(siran_pin, OUTPUT); // Siran mode pin
  pinMode(LED_PIN, OUTPUT); // LED pin for indication
  digitalWrite(PC13, HIGH); // Turn off LED initially (active low)
  digitalWrite(siran_pin, LOW); // Disable Siran mode initially
  digitalWrite(LED_PIN, LOW); // Turn off LED initially

  // Initialize radio
  if (!radio.begin()) {
    DebugSerial.println("Radio hardware not responding!");
    while(1); // Hold in infinite loop
  }
  // Configuration settings.
  radio.setChannel(2);
  radio.setDataRate(RF24_2MBPS); // 2 Mbps
  radio.setPALevel(RF24_PA_LOW); // Set power level
  radio.openReadingPipe(0, (uint8_t*)"gyroc");  // using pipe 0
  radio.setCRCLength(RF24_CRC_16); // Set CRC length
  radio.setAutoAck(true); // enable AutoAck.
  radio.enableDynamicPayloads(); // Enable dynamic payloads
  // END Configuration settings.
  
  radio.startListening();  // put radio in RX mode
  delay(1000); // Allow some time for the radio to initialize
  
  DebugSerial.println("NRF24L01 Receiver Test");
  DebugSerial.println("Pin Configuration:");
  DebugSerial.println("CE  -> PA4");
  DebugSerial.println("CSN -> PA3"); 
  DebugSerial.println("SCK -> PA5");
  DebugSerial.println("MOSI-> PA7");
  DebugSerial.println("MISO-> PA6");
  DebugSerial.println("IRQ -> PA2 (not used)");
  DebugSerial.println("DEBUG TX -> PA9");
  DebugSerial.println("DEBUG RX -> PA10");
  
  // Print radio configuration details
  DebugSerial.println("\nRadio Configuration:");
  DebugSerial.print("Channel: "); DebugSerial.println(radio.getChannel());
  DebugSerial.print("Data Rate: ");
  if (radio.getDataRate() == RF24_2MBPS) DebugSerial.println("2Mbps");
  else if (radio.getDataRate() == RF24_1MBPS) DebugSerial.println("1Mbps");
  else DebugSerial.println("250kbps");
  DebugSerial.print("Power Level: ");
  if (radio.getPALevel() == RF24_PA_LOW) DebugSerial.println("Low");
  else if (radio.getPALevel() == RF24_PA_HIGH) DebugSerial.println("High");
  else if (radio.getPALevel() == RF24_PA_MAX) DebugSerial.println("Max");
  else DebugSerial.println("Min");
  DebugSerial.print("CRC Length: ");
  if (radio.getCRCLength() == RF24_CRC_16) DebugSerial.println("16-bit");
  else DebugSerial.println("8-bit");
  DebugSerial.print("Auto Ack: "); DebugSerial.println(radio.isAckPayloadAvailable() ? "Enabled" : "Disabled");
  DebugSerial.print("Dynamic Payloads: "); DebugSerial.println("Enabled");
  
  DebugSerial.println("Listening for data...");
  DebugSerial.println("Waiting for incoming transmissions...");
  DebugSerial.println("Expecting messages with 4-byte header + 20-byte data format");
  DebugSerial.println("USB Serial: JSON output only");
  DebugSerial.println("Debug Serial (PA9/PA10): Debug messages");
}  // setup
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
